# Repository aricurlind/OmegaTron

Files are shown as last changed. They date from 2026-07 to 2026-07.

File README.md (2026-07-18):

# Omega‑Tron – Autonomous Robot Vehicle  

Omega‑Tron is an autonomous robot vehicle developed as part of the M4000 project at Munich University of Applied Sciences.  
The system integrates **lane detection**, **obstacle avoidance**, **object detection**, **robot‑arm control**, **navigation**, and **inductive charging** into one modular platform powered by a Raspberry Pi 4B and Arduino Nano.

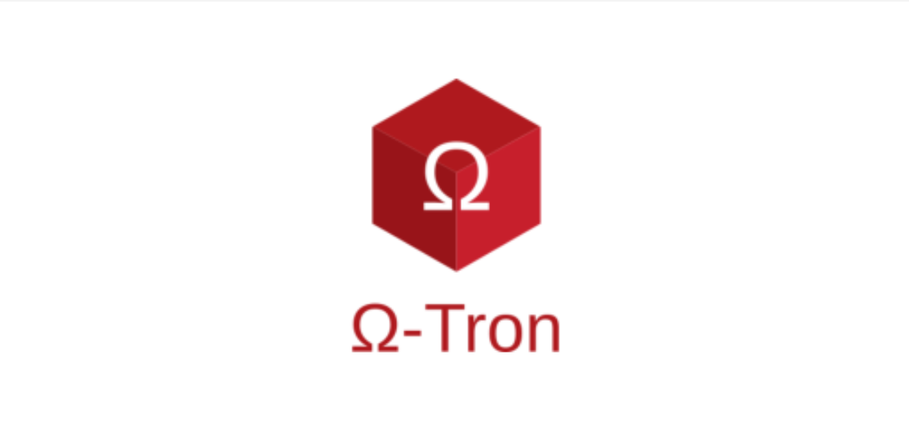
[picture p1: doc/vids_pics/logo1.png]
Omega Tron Logo
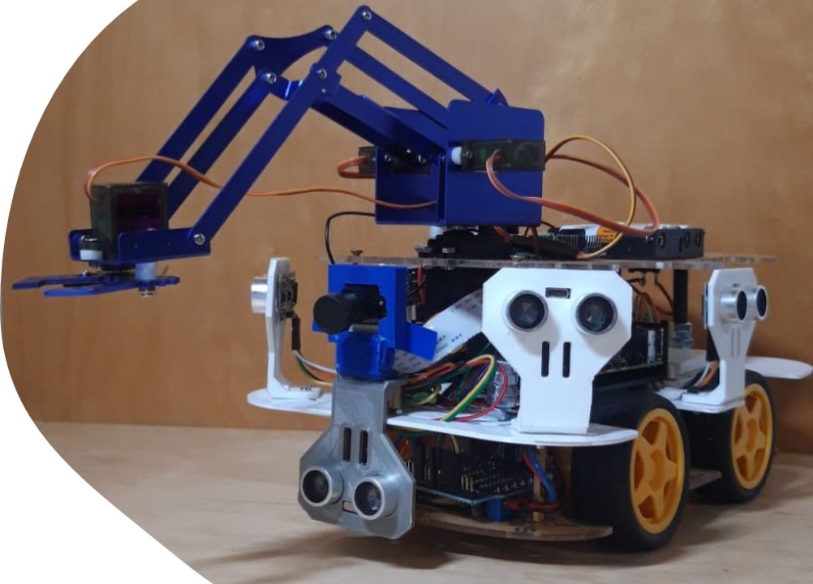
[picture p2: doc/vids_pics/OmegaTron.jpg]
Omega Tron
 

---

> **Note on images/videos below:** several media links in this README will not render on GitHub in their current form.

---

## Table of Contents
- [Project Overview](#project-overview)
- [System Architecture](#system-architecture)
- [Hardware Requirements](#hardware-requirements)
- [Software Requirements](#software-requirements)
- [Setup & Installation](#setup--installation)
- [YOLOv3 Training (Object Detection)](#yolov3-training-object-detection)
- [Running the System](#running-the-system)
- [Modules](#modules)

---

## Project Overview  
Omega‑Tron demonstrates how modern autonomous‑driving concepts can be implemented in a compact robotic system.  
The robot can:

- Detect and follow lanes  
- Avoid obstacles using 5 ultrasonic sensors  
- Identify objects (4 types of waste) using YOLOv3  
- Pick up objects with a 4‑DOF robot arm  
- Navigate using ROS odometry  
- Automatically dock to a charging station using a QR‑code marker
  
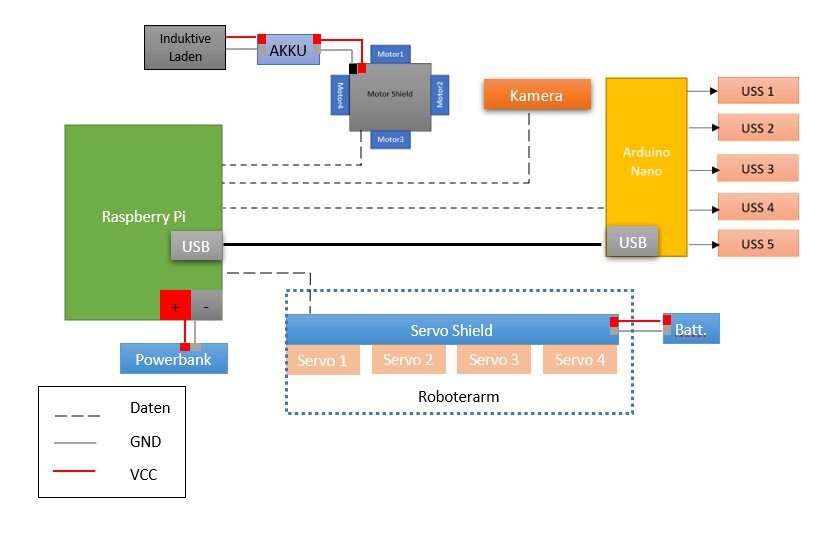
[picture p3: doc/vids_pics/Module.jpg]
Modules

---

## System Architecture  
The project is divided into several functional modules:

- **Lane Detection**  
- **Obstacle Avoidance**  
- **Object Detection**  
- **Robot Arm Control**  
- **Navigation & ROS**  
- **Inductive Charging**  

---

## Hardware Requirements  
### Core components (bill of materials)
| Component | Spec / Notes | Qty |
|---|---|---|
| Raspberry Pi 4B | 4 GB or 8 GB RAM recommended (YOLOv3 + OpenCV are memory-hungry) | 1 |
| microSD card | 32 GB+, A1/A2 rated for acceptable I/O speed | 1 |
| Arduino Nano | ATmega328P, USB-to-serial (CH340 or FTDI) | 1 |
| HC‑SR04 ultrasonic sensor | 2 cm–400 cm range | 5 |
| JOY‑IT DC gear motors | 6 V–12 V, with wheels | 4 |
| Arduino Motor Shield L293D | dual H-bridge, up to 4 DC motors | 1 |
| PCA9685 servo driver | 16-channel, I2C, 6 V servo rail | 1 |
| MG996R / MG905 servos | robot arm joints (base/shoulder/elbow/gripper) | 4 |
| Raspberry Pi Camera Module | v2 (8 MP) or HQ Camera, ribbon cable long enough to mount | 1 |
| Inductive charging coil set (Tx + Rx) | matched pair, 5 V/12 V output depending on design | 1 |
| QR-code marker (printed) | matte paper/laminated, fixed size, mounted at charging dock | 1 |
| Chassis / mounting plates | laser-cut or 3D-printed, drawings in `docs/` | 1 set |
| Battery pack (drive/logic) | separate rails recommended: ~7.4–11.1 V LiPo for motors, 5 V/3 A UBEC for Pi | 1–2 |
| Voltage regulator / UBEC | steps battery voltage down to a clean 5 V for the Pi | 1 |
| Jumper wires, perfboard, JST connectors | for all sensor/motor/servo wiring | as needed |
| USB cable (Pi ↔ Arduino Nano) | serial link for the 5 ultrasonic sensors | 1 |

### Special / non-obvious equipment
- **Soldering iron, solder, heat‑shrink tubing** – most connectors (motor shield, PCA9685, battery leads) are not solder‑free.
- **Multimeter** – required to verify the two power rails (motor vs. logic) before first power-on; a wiring mistake here can kill the Pi.
- **3D printer or laser cutter access** – only needed if you fabricate your own chassis instead of buying an off-the-shelf one; STL/DXF files should be placed in `docs/`.
- **A second computer with a GPU (or a Google Colab account)** – needed for YOLOv3 training, see below. Training on the Raspberry Pi itself is not practical.
- **USB keyboard/mouse + HDMI monitor, or SSH access over Wi‑Fi** – for initial Raspberry Pi OS setup if you don't use headless provisioning.

---

## Software Requirements

### Raspberry Pi (master)
- **OS**: Raspberry Pi OS (Bullseye or newer, 64‑bit recommended) — flashed with Raspberry Pi Imager.
- **Python**: 3.9+
- **Python packages** (see `requirements.txt` per module; consolidated list):
  - `opencv-python` (or `opencv-contrib-python` if you need extra modules)
  - `numpy`
  - `torch`, `torchvision` (CPU build is enough for inference on the Pi; training happens off-device, see below)
  - `pygame` (PS4 controller input during data collection)
  - `pyserial` (serial link to the Arduino Nano)
  - `pandas`, `matplotlib`, `scikit-learn` (lane-following CNN training/data logging)
  - `Adafruit-GPIO`, `RPi.GPIO` (motor shield + PCA9685)
- Interfaces to enable via `sudo raspi-config` before anything else works:
  - **Camera** (`Interface Options → Camera`, or `libcamera` stack on Bullseye+)
  - **I2C** (`Interface Options → I2C`) — required for the PCA9685 servo driver
  - **Serial port** (`Interface Options → Serial Port`) — enable the hardware serial, **disable** the serial login shell, or the Arduino link will fight with a getty process

### Arduino Nano (slave)
- **Arduino IDE** 1.8.x or 2.x, or `arduino-cli`
- Board package: **Arduino AVR Boards**
- No extra libraries needed beyond the built-in `Arduino.h` for the ultrasonic firmware (plain `pulseIn`-based ranging); if you swap in a library-based ultrasonic driver (e.g. `NewPing`), install it via Library Manager.

### Navigation (ROS)
- **ROS Noetic** (Ubuntu 20.04) is the natural fit for a Python-2/3-transition-era project like this; if you're starting fresh today, ROS 2 (Humble/Jazzy) is worth considering instead, but the odometry/mapping instructions in `navigation/` assume ROS 1 conventions (catkin workspace, `roslaunch`).
- ROS typically runs more reliably on a 64-bit Ubuntu Server image on the Pi (or a companion laptop acting as ROS master) than on Raspberry Pi OS; decide this before wiring your network setup.
- Packages: `ros-noetic-navigation`, `ros-noetic-robot-localization` (or equivalents) for odometry/mapping; a `catkin` workspace under `navigation/`.

### YOLO training (done off the robot)
- Python 3.9+ with `torch`, `torchvision` (GPU build) **or** a Google Colab notebook (free GPU, no local install needed)
- A labeling tool: **LabelImg** or **CVAT** or **Roboflow** (any of these can export YOLO-format annotations)
- `opencv-python`, `numpy`, `matplotlib` for dataset inspection/augmentation

---

## Setup & Installation

1. **Flash the Pi**
   Flash Raspberry Pi OS with Raspberry Pi Imager, boot, run `sudo raspi-config` and enable Camera, I2C, and Serial (hardware port on, login shell off) as listed above. Reboot.

2. **Clone the repository**
   ```bash
   git clone <this-repo-url> Omega-Tron
   cd Omega-Tron
   ```

3. **Python environment**
   ```bash
   python3 -m venv .venv
   source .venv/bin/activate
   pip install -r requirements.txt
   ```

4. **Wire the hardware**
   Follow the wiring diagram in `docs/` for: motor shield → DC motors, PCA9685 → servos, HC‑SR04 sensors → Arduino Nano, Arduino Nano → Pi (USB), camera → Pi camera port. Double‑check the two power rails with a multimeter before connecting the Pi.

5. **Flash the Arduino Nano**
   Open `obstacle_avoidance/uss_slave/uss_slave.ino` in the Arduino IDE, select **Board: Arduino Nano** and the correct **Port**, then upload. Confirm with the Serial Monitor (9600 baud) that five distance values are being printed in a loop.

6. **Calibrate the classical lane detector**
   Run the lane-detection script with its trackbar window enabled and adjust the bird's-eye-view region and HSV thresholds for your track/lighting before trusting the output.

7. **(Optional) Set up ROS for navigation/docking**
   Install ROS Noetic (or your chosen distro) on the Pi or companion computer, build the `navigation/` catkin workspace, and confirm odometry topics are publishing before attempting autonomous docking.

8. **Place trained YOLO weights**
   Copy your trained `.weights`/`.pt` and `.cfg`/class-name files into `object_detection/` (see training section below) — the repo does not ship pretrained weights.

---

## YOLOv3 Training (Object Detection)

The object detector is **not trained on the robot**. Typical workflow:

1. **Collect images** of the 4 target waste classes under conditions similar to the robot's camera (angle, lighting, background).
2. **Label** the images in YOLO format (one `.txt` per image with `class x_center y_center width height`, normalized) using LabelImg, CVAT, or Roboflow.
3. **Split** the dataset into train/val (and ideally a held-out test set).
4. **Train**:
   - Easiest path: open the provided training notebook in **Google Colab** (free GPU), mount your dataset from Google Drive, and run the training cells — no local GPU required.
   - Local path: install a CUDA-capable PyTorch build and run the training script on your own GPU machine.
5. **Export** the resulting weights and config/class files.
6. **Deploy**: copy the exported files into `object_detection/` on the Pi. Inference on the Pi runs on CPU (or via OpenCV's DNN module), so keep the input resolution modest (e.g. 320×320) to maintain a usable frame rate.

---

## Running the System

Exact entry points depend on what's committed under each module folder; as a general pattern:

```bash
# Obstacle avoidance only (bench test)
python3 obstacle_avoidance/uss_master.py

# Lane following only
python3 lane_detection/lane_main.py

# Full autonomous run (lane + obstacle + object pickup)
python3 main.py
```

Run each module standalone first to verify sensors/actuators individually before running the combined `main.py` — this saves a lot of debugging time when something is miswired.

---
## Modules

### Lane Detection  

**Classical approach** 

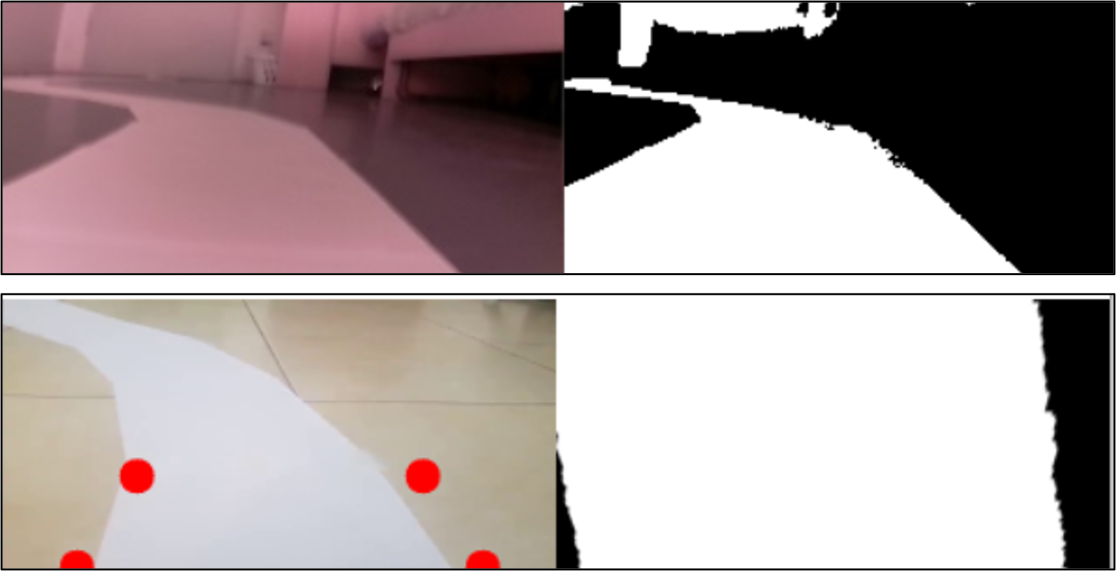
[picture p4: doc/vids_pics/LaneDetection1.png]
LaneDetection1


- Canny edge detection  
- Bird’s‑eye transformation  
- Histogram‑based lane center estimation  
- Hough transform for line detection  

📹 Demo video: [Media1](doc/vids_pics/Media1.mp4)

**Deep learning approach**

- Data collection during driving  
- CNN training on lane images  
- Output: steering angle prediction  

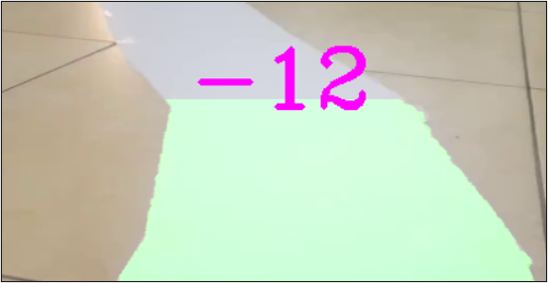
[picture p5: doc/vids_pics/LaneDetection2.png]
LaneDetection2
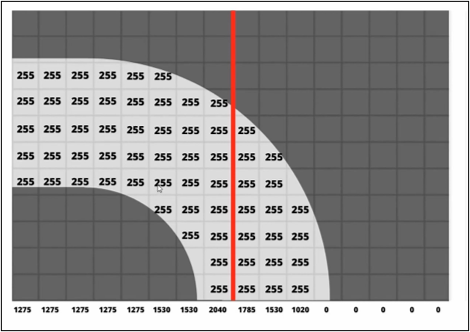
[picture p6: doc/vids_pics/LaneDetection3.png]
LaneDetection3
 

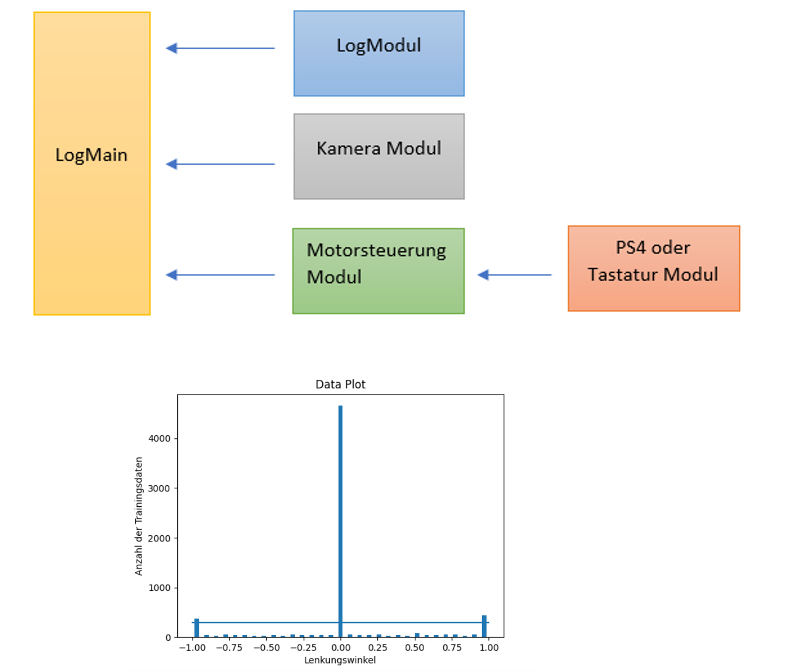
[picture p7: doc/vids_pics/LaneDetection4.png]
LaneDetection4

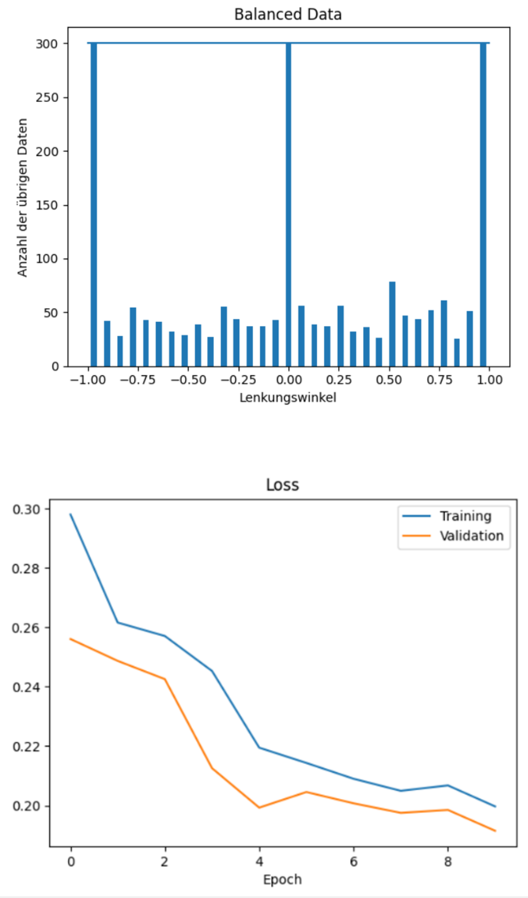
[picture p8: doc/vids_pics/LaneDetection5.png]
LaneDetection5


📹 Demo videos: [Media2](doc/vids_pics/Media2.mp4) · [Media3](doc/vids_pics/Media3.mp4)

---

### Obstacle Avoidance  

DistanceSensors2 

- 5 ultrasonic sensors controlled by Arduino Nano  
- Encoded distance values sent to Raspberry Pi  
- Python master interprets sensor data  
- Motor control decisions via AMSpi  

---

### Object Detection  

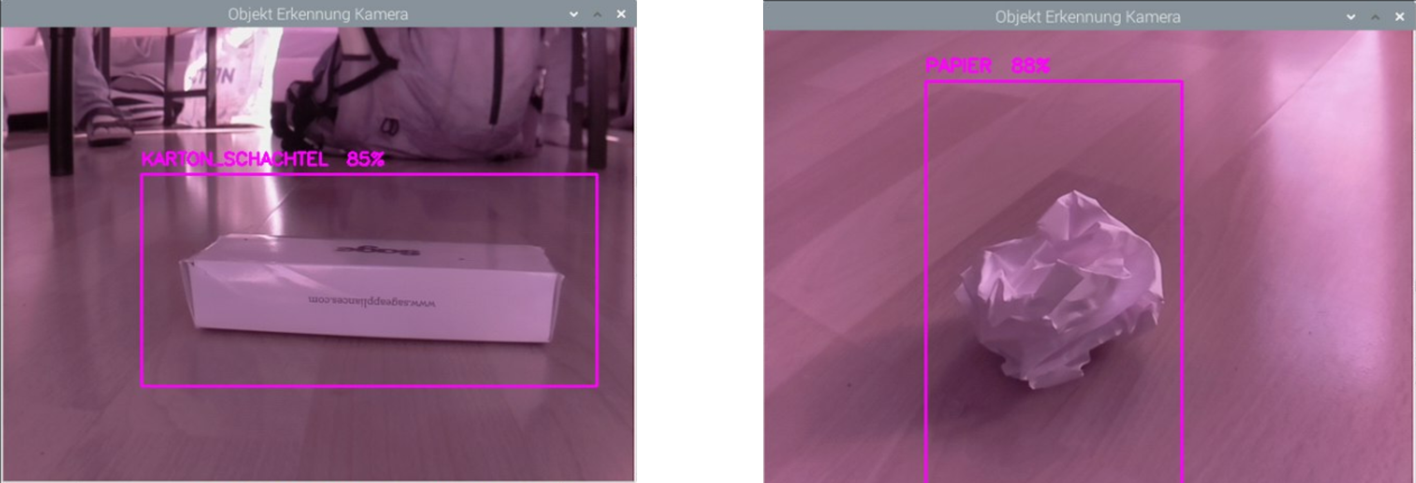
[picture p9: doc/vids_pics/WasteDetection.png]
WasteDetection
 

YOLOv3 identifies trash objects and provides bounding boxes.  
Detected coordinates are forwarded to the robot arm module.

---

### Robot Arm  

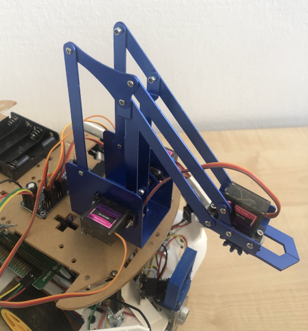
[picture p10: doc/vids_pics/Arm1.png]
RobotArm
 

- 4 degrees of freedom  
- MG996R / MG905 servos  
- PCA9685 for precise PWM control  
- Automated grasping based on object position  

📹 Demo video: [Media4](doc/vids_pics/Media4.mp4)

---

### Inductive Charging  
- Battery monitoring via GPIO  
- ROS navigation to charging station  
- Final alignment using QR‑code detection  

---

## 👥 Authors  
- Arlind Çurumi       - Team and SW Lead
- Christoph Häußler   - HW Integration Lead
- Jiang Qi Qiu  
- Ismail Güney  
- Munich University of Applied Sciences – Faculty of Mechanical Engineering - Mechatronics Laboratory

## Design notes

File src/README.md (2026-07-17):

# Omega-Tron – Autonomes Roboterauto

## Projektstruktur

```
OmegaTron/
├── main.py                       # Verbindet Fahrspurfolge, Hindernisumfahrung und Müllsammlung
├── requirements.txt               # Laufzeit-Abhängigkeiten (Pi)
├── requirements-dev.txt           # + pytest für Entwicklung/Tests auf einem PC
├── Common/
│   ├── config.py                 # Zentrale Konfiguration (Schwellwerte, Regler-Gains)
│   ├── pid.py                    # Generischer PID-Regler mit Anti-Windup
│   ├── filters.py                # Median- und Kalman-Filter für Sensordaten
│   └── video_stream.py           # Threaded Kamera + feste Regelschleifen-Taktung
├── tests/                        # pytest-Suite mit gemockter Hardware (RPi.GPIO, cv2)
│   ├── conftest.py
│   ├── test_pid.py
│   ├── test_filters.py
│   ├── test_ultraschallsensoren.py
│   ├── test_motortreiber_mixing.py
│   └── test_waste_collector.py
│
├── Motorsteuerung/
│   ├── AMSpi.py                  # Open-Source Bibliothek für Arduino Motor Shield L293D
│   ├── Motortreiber.py           # Fahrbefehle (vorwärts, rückwärts, links, rechts, ...)
│   └── hand.py                   # Manuelle Tastatursteuerung via Pygame
│
├── Hindernisumfahrung/
│   ├── USS_Master.py             # Raspberry Pi Master – liest serielle USS-Daten und steuert Motoren
│   └── USS_5.ino                 # Arduino Nano Slave – liest 5 Ultraschallsensoren
│
├── Fahrspurerkennung/
│   ├── AlgorithmusOhneDL/
│   │   ├── LaneDetection.py      # Hauptskript – Fahrspurerkennung ohne Deep Learning
│   │   ├── Hilfsfunktionen.py    # HSV-Filter, Warping, Histogramm, Visualisierung
│   │   └── Farbengenerator.py    # Tool zum Einstellen der HSV-Grenzwerte
│   │
│   ├── Datensammlung/
│   │   ├── LogMain.py            # Hauptskript – Bilder + Lenkwerte aufzeichnen (PS4-Controller)
│   │   ├── LogModul.py           # Speichert Bilder und CSV-Log
│   │   └── KameraModul.py        # Kamera-Wrapper
│   │
│   ├── Training/
│   │   ├── Training.py           # CNN-Training nach NVIDIA-Architektur
│   │   └── Hilf_Func.py          # Datenladen, Augmentation, Preprocessing, Modell, Generator
│   │
│   └── MitDL/
│       └── Omega_Tron_CNN_Main.py  # Autonome Fahrt mit trainiertem CNN-Modell
│
├── Objekterkennung/
│   ├── Obj_Detection.py          # YOLOv3-Erkennung + Bounding Box Anzeige
│   ├── Detection_Modul.py        # Schnittstelle Kamera → Erkennung → Roboterarm
│   └── train_yolov3_custom.py    # YOLOv3-Training in Google Colab (kommentiert)
│
└── Roboterarm/
    ├── Adafruit_PCA9685.py       # PWM-Controller-Bibliothek für PCA9685
    └── ModulRoboterarm_aktuell.py  # Roboterarm-Steuerung (Start, Greifen, Wegwerfen)
```

## Hardware

- Raspberry Pi 4B (Master)
- Arduino Nano (Slave – Ultraschallsensoren)
- Arduino Motor Shield L293D
- 4x DC-Motoren
- 5x Ultraschallsensoren (USS)
- Raspberry Pi Kamera
- PCA9685 PWM-Controller
- 4-DOF Roboterarm mit Servos
- PS4-Controller (für manuelle Steuerung / Datensammlung)

## Erkannte Objektklassen

| ID | Klasse |
|----|---|
| 0  | Bio-Müll |
| 1  | Metallische Dose  |
| 2  | Papier |
| 3  | Karton/Schachtel  |
| 4  | Plastik |

## Regelung, Filterung & Nebenläufigkeit

- **PID statt Bang-Bang**: Fahrspurlenkung (main.py) und Objektzentrierung
  (Detection_Modul.py) verwenden `Common/pid.py` statt fester
  Geschwindigkeit "Richtung Fehler". Gains sind Startwerte und müssen am
  Fahrzeug getunt werden.
- **Sensorfilterung**: Jeder Ultraschallsensor läuft durch einen eigenen
  Medianfilter (`Common/filters.py`), der einzelne Fehlmessungen abfängt.
  Ein Kalman-Filter für ein 1D-Konstantwert-Modell steht ebenfalls bereit.
- **Feste Zykluszeit**: `Common/video_stream.py` entkoppelt die
  Kameraaufnahme (Hintergrundthread) von der Regelschleife und taktet
  Letztere über `FixedRateLoop` auf eine feste Frequenz, da die PID-Regler
  eine konsistente dt erwarten.
- **Recovery-Verhalten**: `Ultraschallsensoren.py` versucht bei
  Verbindungsabbruch einen Reconnect statt abzustürzen;
  `Detection_Modul.py` wiederholt die Greifsequenz bei einem I2C-Fehler,
  bevor sie aufgibt.

## Tests

```bash
pip install -r requirements-dev.txt
pytest tests/
```

Hardwareabhängige Module (RPi.GPIO, cv2) werden in `tests/conftest.py`
gemockt, damit die reine Logik (PID, Filter, Decodierschema, Mixing-Mathematik,
State Machine) ohne Pi/Kamera/Arduino läuft.

## ML-Training

`Fahrspurerkennung/Training/` nutzt inzwischen einen echten
Train/Val/Test-Split, Dropout/BatchNorm, EarlyStopping und
ReduceLROnPlateau. Jeder Lauf legt unter `runs/<timestamp>/` sein Modell,
den Trainingsverlauf (`history.csv`) und die verwendeten Hyperparameter
(`config.json`) ab – kein vollwertiges Experiment-Tracking wie MLflow/W&B,
aber genug, um Läufe nachvollziehen zu können.

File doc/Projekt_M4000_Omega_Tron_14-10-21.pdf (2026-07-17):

## Hochschule München University of Applied Sciences

## Fakultät für Maschinenbau, Fahrzeugtechnik und Flugzeugtechnik

### Projektarbeit M4000

### Entwicklung und Programmierung von Modellrobotern

# Ω-Tron

Verfasser : | Çurumi, Arlind
| Häußler, Christoph
| Qiu, Jiang Qi
| Güney, Ismail
Studiengang: | Maschinenbau, MBB 6
Betreuer: | Prof. Dr. T. Küpper
| Prof. Dr. J. Reichel
Abgabetermin: | 13.10.2021

## Inhaltsverzeichnis

6.5 Datenblätter | Fehler! Textmarke nicht definiert.

### 1 Einleitung

### 1.1 Aktuelle Entwicklungstrends im Bereich Autonomes Fahren

Die Automobilindustrie befindet sich in einem massiven und komplexen, vor allem aber sehr dynamischen Wandel. Die Entwicklung neuer Fahrtechnologien, die Digitalisierung und das Aufkommen neuer Geschäftsmodelle haben diesen Veränderungsprozess bestimmt und ein einzelnes Auto zu einem Kommunikationselement gemacht, das über Internet, Sensoren und Kameras mit seiner Umwelt interagiert. Dadurch können neue Player in den Markt eintreten und die Automobilindustrie von Grund auf verändern. Der harte, globale Wettbewerb um den Markt von morgen hat bereits begonnen.

Seit Anfang des letzten Jahrzehnts haben sich Automobilhersteller und ihre Zulieferer der Umsetzung des autonomen Fahrens verschrieben. Viele Testfahrzeuge mit unterschiedlichen Assistenzsystemen wurden weltweit in eigens dafür geschaffenen Testgebieten getestet und teilweise auch im realen Straßenverkehr ordnungsgemäß gekennzeichnet. Obwohl der Begriff „Auto“ die eigenständige Fortbewegung eines Fahrzeugs beschrieben hat, haben selbstfahrende Autos den Begriff der Autonomie präzisiert und in eine neue Dimension gehoben.

Selbstfahrende Autos bewegen sich durch das Zusammenspiel von Mikroprozessorsystemen, Sensoren und Aktoren gezielt selbstständig. Um autonomes Fahren zu realisieren, müssen viele technische Herausforderungen bewältigt werden.

Videokameras der Umgebung , Verkehrszeichen und anderen Teilnehmern. Außerdem helfen sie dem autonomen System, die Entfernung zu Objekten richtig einzuschätzen

Radarsensoren messen den Abstand zu anderen Verkehrsteilnehmern und Objekten. Low- und
High-Range-Sensoren | berechnen | dabei | die
unterschiedlichen | Entfernungen. | Deshalb

benötigt ein Auto mehrere davon - an verschiedenen Stellen. Lidar-Sensoren (Light Detection and Ranging) (https://de.wikipedia.org/wiki/Lidar) auf dem Dach tasten die vorausliegende Strecke ab. Das optische Messsystem feuert für den Menschen unsichtbare Laserstrahlen ab und berechnet den Weg der von einem Hindernis reflektierten Rückstrahlen. Lidar-Sensoren verwenden zur Messung Laserstrahlen statt Radiowellen, wie beim Radar. Ihr Vorteil: die hohe Reichweite.

Mit einem GPS-System wird das Auto genau geortet. Das System weiß immer, wo es sich gerade befindet - nicht nur auf welcher Straße, sondern auch auf welcher Spur. Das ist für abbiegende Fahrzeuge entscheidend.

Doch ein Autonomes Fahrzeug ist weitaus mehr als eine reine Fortbewegungsmittel. Sie kann auch als eine komplettes Mobilitätskonzept, aus dem wir neue Geschäftsmodelle entwickeln können,

Abbildung 1: Sensortopologie für Autonome Fahrzeuge entwickelt werden. Sie kann individuell konfiguriert werden damit Sie für alle Aufgabenstellungen innerhalb des Urbanen Umfelds einsetzbar sein kann.

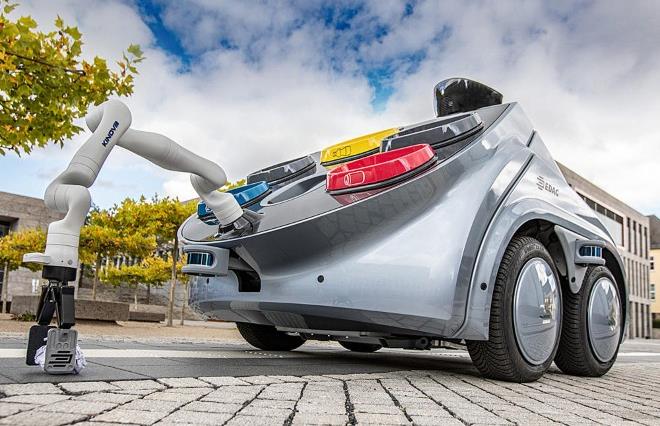
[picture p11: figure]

Abbildung 2: Edag Citybot ©Edag

Solche vernetzten vollautonom fahrenden Roboterfahrzeuge werden zum Beispiel zur Abfallsammlung und Straßenreinigung genutzt. Das Roboterfahrzeug bekommt eine Information, wo welcher Mülleimer zu leeren ist, fährt autonom dort hin und erledigt diese Aufgabe selbstständig. Er kann die unterschiedlichen Abfallsorten durch Künstliche Intelligenz einsortieren und somit richtig entsorgen.

Weitere Konfigurationsmodelle, sind z.B. Roboterfahrzeuge, welche die Post zustellen wie der Roboter-Postbote von Amazon oder das multimodale Citybot-Konzept von EDAG .

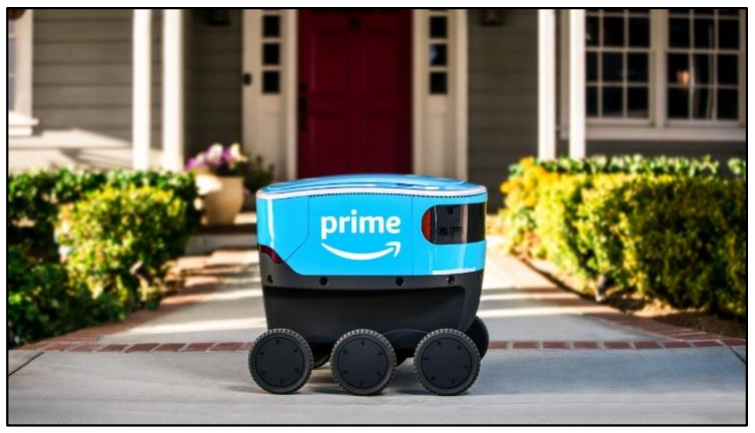
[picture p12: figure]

Abbildung 3: Amazon Scout Postbote ©Amazon

Aufgrund des breiten Anwendungsbereichs und dem wachsenden Interesse an Themen wie autonomes Fahren, Bilderkennung und künstliche Intelligenz haben wir uns dazu entschieden, diese Themenbereiche auch in unserer Projektarbeit zu bearbeiten. Wir hoffen darauf, dass wir uns durch die praktischen Erfahrungen wichtige Kompetenzen für die Zukunft aneignen zu können.

### 1.2 Projektumfang und Kurzfassung

Ziel dieser Projektarbeit ist es, die aktuellen Entwicklungstrends aus dem Bereich autonomes Fahren, in einem Miniroboter Modellauto auf Basis von Raspberry Pi umzusetzen. Als Rechner Einheit wird ein Raspberry Pi 4B eingesetzt, welches das zentrale Element zur Steuerung der verschiedenen Module ist. Umfang der Projektarbeit war es, die elektrische Verschaltungen auszulegen, sowie Module für die Motorsteuerung, eine Fahrspurerkennung, Objekterkennung, die Steuerung des Roboterarms, Ermittlung des Ladezustands, Ansteuerung der Ultraschallsensoren und der Navigation des Roboters zu programmieren.

### 2 Projektplanung

### 2.1 Anforderungen und Zielsetzung

Die Anforderungen und die Zielsetzung wurde durch eine Untergliederung des Gesamtsystems ermittelt. Hierfür wurden die drei Teilsysteme Roboterauto, Objekterkennung und der Roboterarm spezifiziert. Die Schnittstellen haben sich durch diese Spezifizierung folgendermaßen ergeben:

Schnittstelle Roboterauto – Fahrspurerkennung

Schnittstelle Roboterauto – Hindernisumfahrung

Autonomes Fahren

Das Roboterauto hat als Hauptaufgabe in erster Linie die Vorwärts-, Rückwärts- und Seitenbewegung zu gewährleisten. Ziel ist es, am Ende ein voll autonom fahrendes Auto inklusive folgende Anforderungen aufzubauen:

- Hindernisumfahrung
- Fahrspurerkennung
- Objekterkennung

Abfallsammlung

Der Roboterarm ist ein auf dem Roboterauto aufgebautes System, welches vor allem für die Funktion des Greifens verantwortlich ist. Hierbei wird insbesondere durch die Schnittstelle Objekterkennung und Roboterarm Abfall aufgesammelt und entsorgt. Abgesehen vom Greifen ist es besonders wichtig, dass auch der Roboterarm automatisiert und ohne manuelle Bedienung funktioniert und den Greiferarm nutzen kann.

### 2.2 Konzeptideen

2.2.1 Fahrspurerkennung

Für das autonome Fahren wurde ein Algorithmus zur Fahrspurerkennung entwickelt. Dieser Algorithmus basiert auf der Hough Transformation, ein robustes Verfahren zur Erkennung von beliebigen geometrischen Figuren in einem binären Gradienten Feld. Hier handelt es sich um Geradenerkennung und berechnung der mittleren Spur zur Fahrspurverfolgung. Des weiteren wurden Datensätze gesammelt und mit ihnen trainiert, um den Roboter das Fahren einzulernen. Dafür wird ein vereinfachter CNN-Ansatz verwendet.

2.2.1.1 Bild Verarbeitung

Die Fahrspurerkennung ist einer der zentralen Bestandteile von autonomen Fahrzeugen. Es gibt viele Ansätze, um einen Fahrspurerkennung Algorithmus auszulegen. Dabei handelt es sich um das automatisierte Identifizieren der eigenen Fahrspur durch Fahrbahnmarkierungen oder andere Umgebungsmerkmale, die durch verschiedene Sensoren- und Kameras erfasst werden. Auf dem Markt gibt es einige Fahrzeuge, die über diese beiden Funktionen verfügen, nämlich den Abstandsregeltempomat (ACC) und einige Formen von Spurhaltesystemen (LKAS). Der Abstandsregler nutzt verschiedene Radarsensoren, um einen sicheren Abstand zum vorausfahrenden Fahrzeug zu erkennen und einzuhalten, während die Spurhalteassistenzsysteme mittels Kameras die Fahrspur erkennen und das Fahrzeug so lenken, dass es in der Mitte der Fahrspur bleibt.
In diesem Projekt wird ein einfacher Algorithmus zur Erkennung von parametrisierbaren geometrischen Figuren in einem binären Gradienten Bild nach einer Farbenerkennung der der Fahrspur verwendet. Dadurch wird eins einfaches und robustes Konzept zur Erkennung der Fahrspur entwickelt.

Es wurden insgesamt zwei Algorithmen entworfen, welche beide auf die Hough Transformation basieren.

Die erste Algorithmus beinhaltet die folgenden Schritte:

(1) Bildverarbeitung zum Erkennen der Fahrspur durch Kannten Erkennung
(2) Kanten Erkennung Algorithmus (Canny Edge Detektion)
(3) Ausblenden von Bildbereichen, die nicht gewünscht sind (z.b. Objekte auf Seiten der Fahrspur)
(4) Hough Transformation Algorithmus
(5) Erzeugen von Fahrspurbegrenzungslinien zum Bilden der linken und rechten Fahrspur (Abb.4)

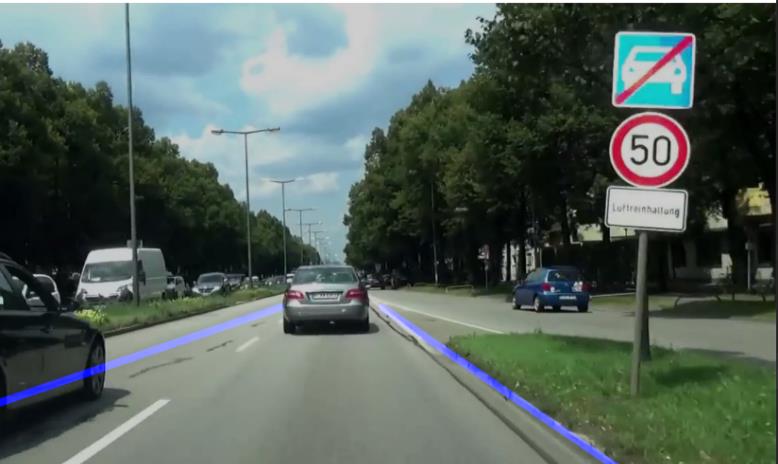
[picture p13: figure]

Abbildung 4: Fahrspurverfolgung durch Kantenerkennung mit Hough Transformation Quelle: Eigene Darstellung

Der zweite Algorithmus beinhaltet die folgenden Schritten(Abb.5):

(1) Bildverarbeitung zum Erkennen der Fahrspur durch Farbenunterschiede (Color Detection)
(2) Kamerabildtransformation in Vogelperspektive (Birdseyeview)
(3) Pixelaufsummierung zum Identifizieren der Fahrspur
(4) Bestimmung der Fahrspurmittellinie

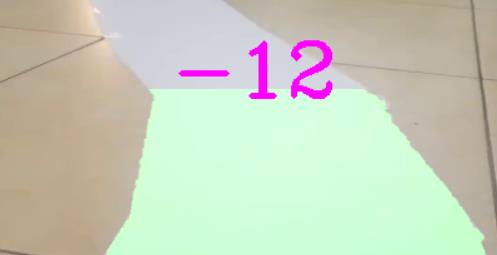
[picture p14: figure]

Abbildung 5: Fahrspurerkennung durch Farbenerkennung. Quelle: Eigene Darstellung

2.2.1.2 Convolutional Neural Networks

Deep Learning ist ein Teilbereich des maschinellen Lernens, der sich mit Algorithmen befasst, die von der Struktur und Funktion des Gehirns inspiriert sind und als künstliche neuronale Netze bezeichnet werden. Im maschinellen Lernen werden Algorithmen, um eine bestimmte Aufgabe zu erledigen, ohne explizit programmiert zu werden. Anders als im maschinellen Lernen, sind Deep Learning Modelle in der Lage von sich aus zu lernen. Das passiert, in dem die Systeme das Erlernte immer wieder mit neuen Inhalten verknüpfen und dadurch erneut lernen. Bei Lernvorgang von neuronalen Netzen wird das Analysieren der neuen Daten der Maschine überlassen.

Deep-Learning Algorithmen sind Tiefe neuronale Netze und bestehen aus vielen Schichten aus linearen und nicht linearen Datenverarbeitungseinheiten.

In diesem Projekt wird auch eine Deep Learning Model angewendet, um den Modellroboter das Fahren einzulernen. Das verwendete Modell ist Convolutional Neural Network.

Ein CNN (Convolutional Neural Network) ist eine besondere Form der künstlichen Neuronalen Netzwerks die in der Bildverarbeitung und -erkennung verwendet wird. Sie ist speziell für die Verarbeitung von Pixel-Daten konzipiert.

Bei CNN Modellen werden die Eingabebilder verarbeitet und auf Bestimmten Kategorien klassifiziert. Diese Eingabebilder werden vom Computer als eine Matrix von Pixeln interpretiert. Die Größe dieser Matrix ist von Bildauflösung Abhängig.

Jedes Eingabebild, wie in Abb.6 zu sehen ist, läuft eine Reihe von verschiedenen Faltungsschichten (Eng. Layer) durch.

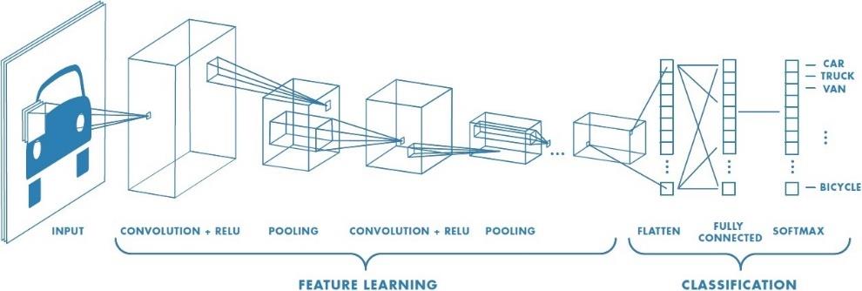
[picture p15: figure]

Abbildung 6: CNN Schichten

Die „Convolutional Layer“ ist die erste Schicht zur Extraktion von Merkmalen aus einem Eingangsbild. Diese Layer-Schicht bewahrt die Beziehung zwischen Pixeln, indem sie Bildmerkmale anhand kleiner Quadrate von Eingabedaten lernt. Es handelt sich um eine mathematische Operation, die zwei Eingaben wie eine Bildmatrix und einen Filter oder Kernel benötigt.

Die Schichten einer CNN sind eine Kombination aus Faltungsschichten, Pooling-Schichten, Normalisierungsschichten und vollständig verbundenen Schichten. CNNs verwenden mehrere Faltungsschichten, um Eingabevolumen auf einem höheren Grad an Abstraktion zu filtern. CNNs verbessern ihre Erkennungsfähigkeit für ungewöhnlich platzierte Objekte, indem sie Pooling-Schichten für eine begrenzte Translations- und Rotationsinvarianz verwenden. Pooling ermöglicht auch die Verwendung von mehr Faltungsschichten, indem es den Speicherverbrauch reduziert. Normalisierungsschichten werden verwendet, um lokale Eingangsbereiche zu normalisieren, indem alle Eingaben in einer Schicht auf einen Mittelwert von Null und eine Varianz von Eins gebracht werden.

Andere Techniken zur Anpassung wie z.b. „Batch“-Normalisierung bei der die Aktivierungen für den gesamten Faltungssatz normalisiert werden, oder die Dropout-Technik, bei der zufällig ausgewählte Neuronen während des Trainingsprozesses ignoriert werden, können ebenfalls verwendet werden.

Im Kapitel 3.4.2.2 Training der Daten wird nochmal an das Training mit CNN angegangen und die einzelnen inneren Prozesse einer CNN-Modell nochmal mit Beispielen aus der trainierten Fahrspurerkennungsmodell der Omega-Tron erläutert.

2.2.2 Hindernisumfahrung (Obstacle Avoidance)

Wie im Abschnitt 2.2.1.1 erwähnt, verwendet man verschiedene Radarsensoren und Kameras beim Autonomen Fahren verwendet, um die Fahrspurerkennung zu ermöglichen. Um ein Fahrspurhaltesystem zu entwickeln, braucht man verschiedene Kameras und einen Algorithmus, das fähig ist Daten zuverlässig und in Echtzeit zu verarbeiten. Für den Abstandsregeltempomat (ACC) braucht man keine Kameras, jedoch wird hier auch ein Algorithmus benötigt. Dies wird benötigt um verschiedene Sensoren wie Radar-, Lidar- und Ultraschallsensoren zu steuern. Die verschiedenen Sensoren dienen dazu die Position und Geschwindigkeit des vorausfahrenden Fahrzeugs zu ermitteln.

In diesem Projekt wurde ein einfacher Algorithmus zur Erkennung von Objekten, die relativ nah zum Omega-Tron sind, verwendet. Dafür wurden keine hochwertigen Sensoren wie Radaren oder Lidar verwendet, sondern nur Ultraschallsensoren. Davon wurden 5 Stück um das Auto montiert und um den Robotermodell so montiert, dass man eine volle Abdeckung des Fahrzeugs hat.

Für das Umsetzen des Konzeptes wurden 2 Konzepte entworfen:

(1) Steuern aller 5 Sensoren über Raspberry Pi
(2) Steuern aller Sensoren von Arduino Nano und das Herstellen einer Master-Slave Kommunikation zwischen Raspberry Pi 4 und Arduino Nano.

Für das erste Konzept wird eine einfache Steuersoftware in Python benötigt, sowie ein Spannungswandler. Da Raspberry Pi mit 3.3V Logik arbeitet und die Ultraschallsensoren aber eine 5V Logik haben, wird eine entsprechenden Anpassung des Spannungsniveaus benötigt.

Abbildung 7: Verbindung der Raspberry Pi mit 5 USS

Beim zweiten Konzept werden die Ultraschallsensoren von einem Microcontroller gesteuert. Da der Arduino Nano eine 5V Logik hat, wird hier kein Spannungswandler benötigt. In Abb.8 sieht man die serielle Verschaltung des Raspberry Pi mit einem Arduino Nano über ein USB-Kabel.

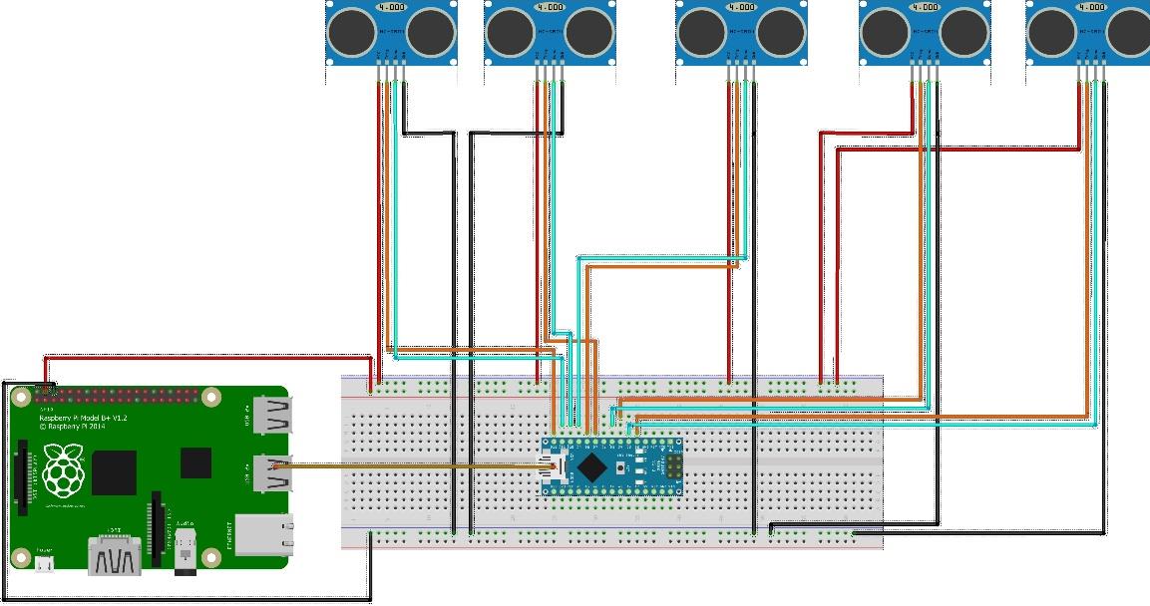
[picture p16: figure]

Abbildung 8: verbindung der Raspberry Pi mit Raspberry Pi Pico (Hier Arduino Nano)

2.2.3 Objekterkennung zur Abfallsammlung

Immer mehr übernehmen Computer in den verschiedensten Gebieten menschliche Aufgaben. Ein großer Bereich ist das maschinelle Lernen von Bilddaten. Egal ob das Erkennen von Fehlern bei der Produktion von SMD Platinen, die Führung eines Fahrzeugs auf der Fahrspur oder ganz groß wie in China: Das Identifizieren von Personen in der Öffentlichkeit, das automatische Erkennen von Objekten findet heute schon ganz große und wichtige Anwendung.

Ganz bekannt und einfach zu verstehen ist Image Classification. Dabei wird dem System ein Bild vorgelegt und dieses soll erkennen, um was es sich auf dem Bild handelt. Objekt Detection geht da noch ein Schritt weiter: Dabei werden um einzelne Objekte sogenannte „Bounding Boxes“ gelegt und einzeln identifiziert.

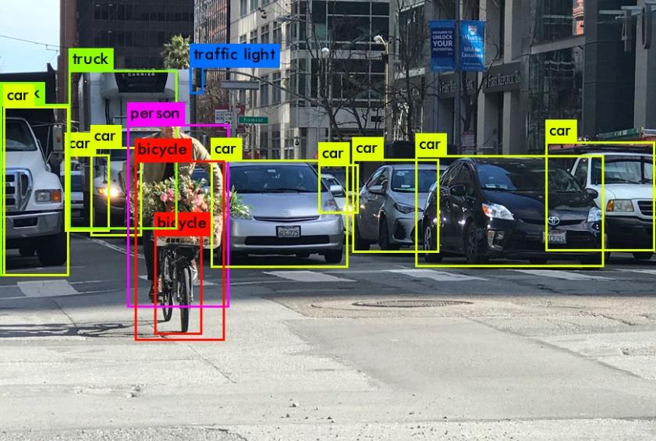
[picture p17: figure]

Abbildung 9: Objekt- und Positionserkennung von Fahrzeugen im Straßenverkehr

YOLO ist eine Möglichkeit, um Objekte zu erkennen. 2016 stellten Redmon, Divvala, Girschick und Farhadi erstmal ihre einstufige Architektur namens „You Only Look Once“ zur Objekterkennung in Echtzeit vor. Durch das Zusammenführen der Lokalisierung und Erkennung mehrerer Objekte innerhalb einer Ebene der Architektur, konnten so schnelle Inferenzzeiten erzeugt werden.

Mittlerweile gibt es verschiedenste Versionen von YOLO. Für unsere Anwendung nutzen wir YOLOv3, welches wie gefolgt funktioniert:

1. Das Bild wird in die Pixelgröße 416x416 Pixeln skaliert und ins Netz eingespeist
2. Dabei durchquert das Bild verschiedenen Schichten von Neuronen
3. Convolutional Network: Neuronen mit einem Filter wie z.B. 3x3 Zelle fährt über das ganze Bild um Merkmale zu erkennen
4. Endauflösung in je 13x13, 26x26 und 52x52 Zellen mit Informationen über das Bild
5. Pro Zelle werden 3 Bounding Boxes gezogen mit je 85 (Geometrie 4, Objekthaftigkeit 1, 80 Klassen) Werten
6. Über 10 000 Bounding Boxes werden durch Non-Maximum Suppression auf wenige reduziert
7. Bounding Boxes mit den schlechtesten Bewertugen werden rausgeschmissen
8. Finale Vorhersage mit je einer Bounding Box und Label

2.2.4 Motorensteuerung

Abbildung 10: Links Getriebe Motor, Rechts Motorshield

Zur Steuerung der vier JOY-IT Getriebemotoren haben wir ein Arduino Motor Shield L293D gewählt welches wir mit Hilfe der Python Klasse AMSpi (https://github.com/lipoja/AMSpi#readme) steuern. Die Klasse verfügt über Befehle zum einzelne Motoren mit Drehrichtung und Geschwindigkeit anzusteuern. Mit diesen Befehlen haben wir eine Motorsteuerung programmiert, mit der man einfache Richtungsbefehle geben kann oder auch eine Geschwindigkeit und einen Lenkwinkel stufenlos vorgeben kann. Mit diesen Befehlen und der Hilfe der pygame Bibliothek, haben wir dann noch ein Programm geschrieben, um den Roboter mit den aus Computerspielen intuitiven Tastatureingaben zu steuern. Die Funktion für Lenkwinkel und Geschwindigkeit wurde noch bei der Fahrspurerkennung genutzt.

2.2.5 Ortung und Navigation

Zur Navigation des Roboters wird ROS(Robot Operating System) verwendet durch ROS erhält man Zugriff auf verschiedenste Module zur Robotersteuerung. Verwendet wird das Odometry Package zur Positionsbestimmung des Roboters. Das Modul vereinigt Eine Integration der Steuerungsdaten sowie Beschleunigungsdaten der IMU(InternalMesurementUnit). Mit Hilfe der Ultraschallsenesordaten mappt das Modul TIAGo den Raum und navigiert autonom durch die selbst erstellte Karte.

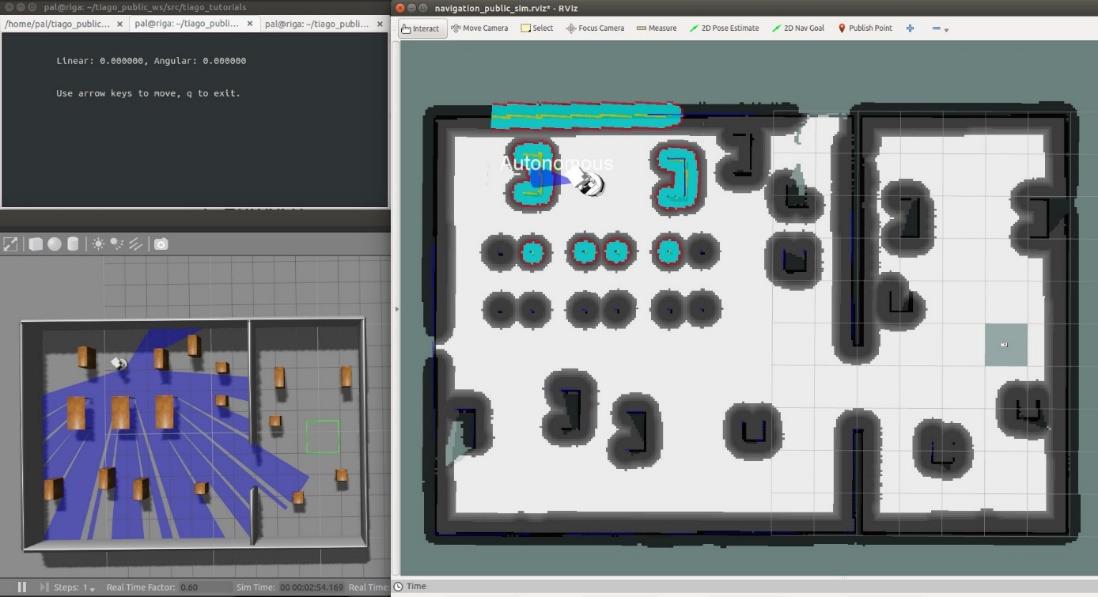
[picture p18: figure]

Abbildung 11: Beispielbild TIAGo Map

2.2.6 Roboterarm

Beim Roboterarm ist die Entscheidung sehr schnell auf einen Greiferarm mit vier Freiheitsgraden und Servomotoren als Antrieb für diese gefallen. Hierbei musste man auf die Art des Servomotors Acht geben, da nicht alle Gelenke des Roboterarms die gleiche Versorgung beziehungsweise manche Gelenke mehr Power als andere benötigen. Hierbei handelt es sich um die Servomotoren MG905 und MG996R. Für die Schnittstelle zum Raspberry Pi wurde der Servotreiber PCA9685 mit 16 Kanälen als beste Lösung auserkoren. Die Verbindung zwischen dem Raspberry Pi und dem Servotreiber wurde über Jumper Kabel realisiert. Die Servomotoren wurden schließlich mit dem Servotreiber verbunden und die Kanäle definiert.

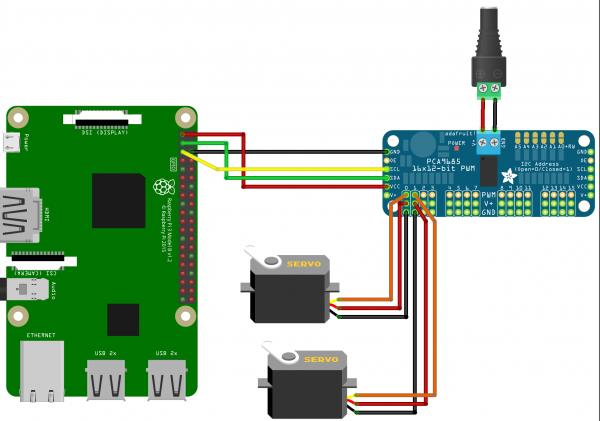
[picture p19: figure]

Abbildung 12: Schaltschema Servomotoren

Des Weiteren war bei der Realisierung wichtig einzuplanen, wo und wie der Roboterarm und der Servotreiber auf dem Auto eingebaut wird. Letztendlich wurde dazu entschieden, den Greifer und Treiber auf die höchste Ebene des Roboters zu montieren.

Abbildung 13: Roboterarm

2.2.7 Induktives Laden
Das induktive Laden wird durch eine Ladespule am Boden des Roboters realisiert. Der Roboter navigiert mit Hilfe der Ordometriedaten/mit ROS grob zur bekannten Position der Ladestation, wenn die mit einem GPIO verbundene Ladeplatine einen niedrigen Akkustand meldet. Die exakte Positionierung findet über die Kamera, die einen QR-Code über der Station erkennt, statt.

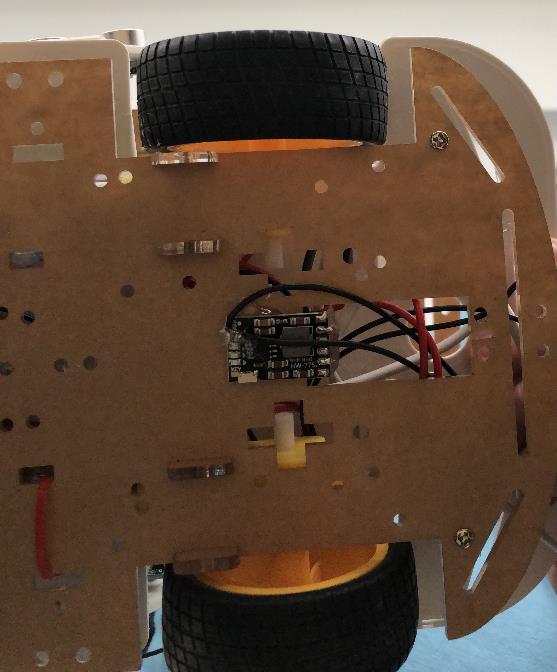
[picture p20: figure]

Abbildung 14: Ladeplatine mit Verkabelung Ladezustandsmessung

### 3 Konzeptentwicklung

### 3.1 Konzeptentwicklung für die Hindernisumfahrung

Beim Entwicklung des Hindernisumfahrung Konzeptes wurde beide Konzept Ideen aus der Konzeptphase ausprobiert und getestet.

Beim Ersten Konzept ging es um eine Steuerung aller 5 Sensoren direkt von Raspberry Pi. Beim Umsetzen und Testen des Steuerungssoftware wurde festgestellt, dass das Senden und Empfangen der Signale vom Raspberry Pi an die Sensoren und Rückwärts viel zu langsam ist. Außerdem gab es Komplikationen bei der Verschaltung der einzelnen Pins von der Ultraschallsensoren zu Raspberry.

Abbildung 15: Raspberry Pi 4 Kommunikation mit USS

Um die Oberen 2 Probleme zu lösen, wurde das zweite Konzept ausprobiert und getestet, nämlich das Steuern der Ultraschallsensoren von einem Microcontroller und das Herstellen einer Master-Slave Kommunikation zwischen den Microcontroller und Raspberry Pi .

Abbildung 16: Raspberry Pi I2C mit Raspberry Pico

Erstmals wurde versucht eine Serielle Kommunikation zwischen den Raspberry Pi und Raspberry PI Pico herzustellen. Es wurde versucht eine I2C Serielle Kommunikation zwischen den beiden Herzustellen. Nach mehreren Testcodes und versuchen hat sich herausgestellt, dass das Herstellen der Kommunikation aufgrund von Bibliotheken Problemen zwischen Python 3 (In Raspberry Pi) und Micro Python (in Raspberry Pico ) nicht möglich war. Da man beim Raspberry Pi Pico au noch in C/C++ programmieren kann wurde auch noch ein letztes Versuch durchgeführt. Hierfür wurde die Programmierungsumgebung von Arduino IDE verwendet. Bei der Steuerung der Sensoren, war das Senden und Empfangen der Daten deutlich schneller, jedoch hat die Kommunikation zwischen Pi und Pico wiederum nicht zuverlässig funktioniert.

Die andere Möglichkeit war das Verwenden einer Arduino Nano zur Steuerung der Sensoren. Die Verbindung der Arduino zu Raspberry wurde mittels USB-Datenkabel ganz simpel und problemlos hergestellt.

Abbildung 17: Raspberry PI Serielle Kommunikation mit Arduino Nano

Die Kommunikation zwischen den Raspberry und dem Arduino lief zuverlässig und reibungslos. Die Serielle Kommunikation wurde auf einen Baudrate von 9600 eingestellt. Über die Python serial() Bibliothek werden die von Arduino Nano Print-Befehle ausgelesen.

Die Werte die Raspberry von Arduino liest werden in die Variable Botschaft gespeichert. Um zu unterscheiden welche Sensor welche Wert geschickt hat, wurde eine ID Wert an die Sensoren zugewiesen. Außerdem wurde in Arduino die Reichweite der Sensoren begrenzt, die können alle jeweils bis 500 cm Reichweite auslesen. Die ID-s wurden wie Folgend definiert:

Sensor Vorne | → | 0 | < | Gelesene Wert | < | 500
Sensor Rechts Vorne | → | 500 | < | Gelesene Wert + 500 | < | 1000
Sensor Links Vorne | → | 1000 | < | Gelesene Wert + 1000 < | 1500
Sensor Rechts | → | 1500 | < | Gelesene Wert + 1500 < | 2000
Sensor Links | → | 2000 | < | Gelesene Wert + 2000 < | 2500

Im Raspberry Pi wurde dann eine Code, die je nach gelesene ID in die Zugehörige Variable die Werte speichert. Um dann das Fahrzeug zu steuern, wurden If-Anweisungen geschrieben, die beim Vergleichen von Entfernungen in eine Definierte Reichweite den Modellroboter lenken.

### 3.2 Computer Vision Schnittstelle

3.2.1 Entwicklung eines Algorithmus zur Fahrspurerkennung

Ein Fahrspurassistenzsystem besteht aus zwei Grundbausteinen, nämlich Fahrspurerkennung (Wahrnehmung der Umgebung) und der Lenkung (Bewegungsplanung).

Die Aufgabe der Fahrspurerkennung besteht darin, ein Video der Straße in die Koordinaten der erkannten Fahrspurlinien umzuwandeln. Um dies zu erreichen, wird des Weiteren das Open-Source Package OpenCV benutzt.

Bevor wir jedoch Fahrspurlinien in einem Video erkennen können, müssen wir in der Lage sein, Fahrspurlinien in einem einzelnen Bild zu erkennen. Sobald wir das können, ist die Erkennung von Fahrspurlinien in einem Video eine einfache Wiederholung der gleichen Schritte für alle Bilder in einem Video.

Um diese Spurhalteassistenzsystem zu entwickeln, wurden die folgenden 5 Schritten benötigt:

i. Bild Verarbeitung zum Erkennen der Fahrspur (Color Detection)

Als erster Schritt muss eine Bildverarbeitungsmethode durchgeführt werden, um die Fahrspur zu erkennen. Dies kann man durch Erkennung von Farbenunterschieden ermitteln.

Da die von der Kamera aufgenommenen Frames einen RGB-Farbenspektrum haben, wird dies in den HSV-Farbenspektrum umgewandelt. Die von OpenCV erfassten Bilder und Videos sind in der Regel im BGR-Format (8-Bit, Ganzzahl ohne Vorzeichen). Anders gesagt können die Erfassten Bilder als 3 Matrizen betrachtet werden: BLAU, ROT und GRÜN mit ganzzahligen Werten zwischen 0 und 255. Bei einem Bild wird jeder einzelne Pixel dann verschiedene Kontrasten von diese 3 Farben haben.

Der Grundgedanke dahinter ist, dass in einem RGB-Bild verschiedene Farben dazu führen, dass die verschiedenen Farben durch Beleuchtungen oder andere Umgebungseinflüsse nicht richtig erkannt werden. In HSV-Farbenspektrum werden alle Objekten aus der Umgebung als Schwarz-Weiß dargestellt. Der HSV-Farbraum besteht aus 3 Matrizen, Hue, Saturation und Value. In OpenCV ist der Wertebereich für die 3 Matrizen jeweils 0-179, 0-255 und 0-255. „Farbton“ (Eng. Hue) steht für die Farbe, „Sättigung“ (Saturation) für den Anteil, in dem die jeweilige Farbe mit Weiß gemischt ist, und „Wert“ (Eng. Value) für den Anteil, in dem die jeweilige Farbe mit Schwarz gemischt ist.

Das macht das Erkennen der Fahrspurlinie Pixel für Pixel viel leichter. Im Abb.5 ist eine Vergleich der Fahrspur in HSV und RGB Farbenspektrum Dargestellt

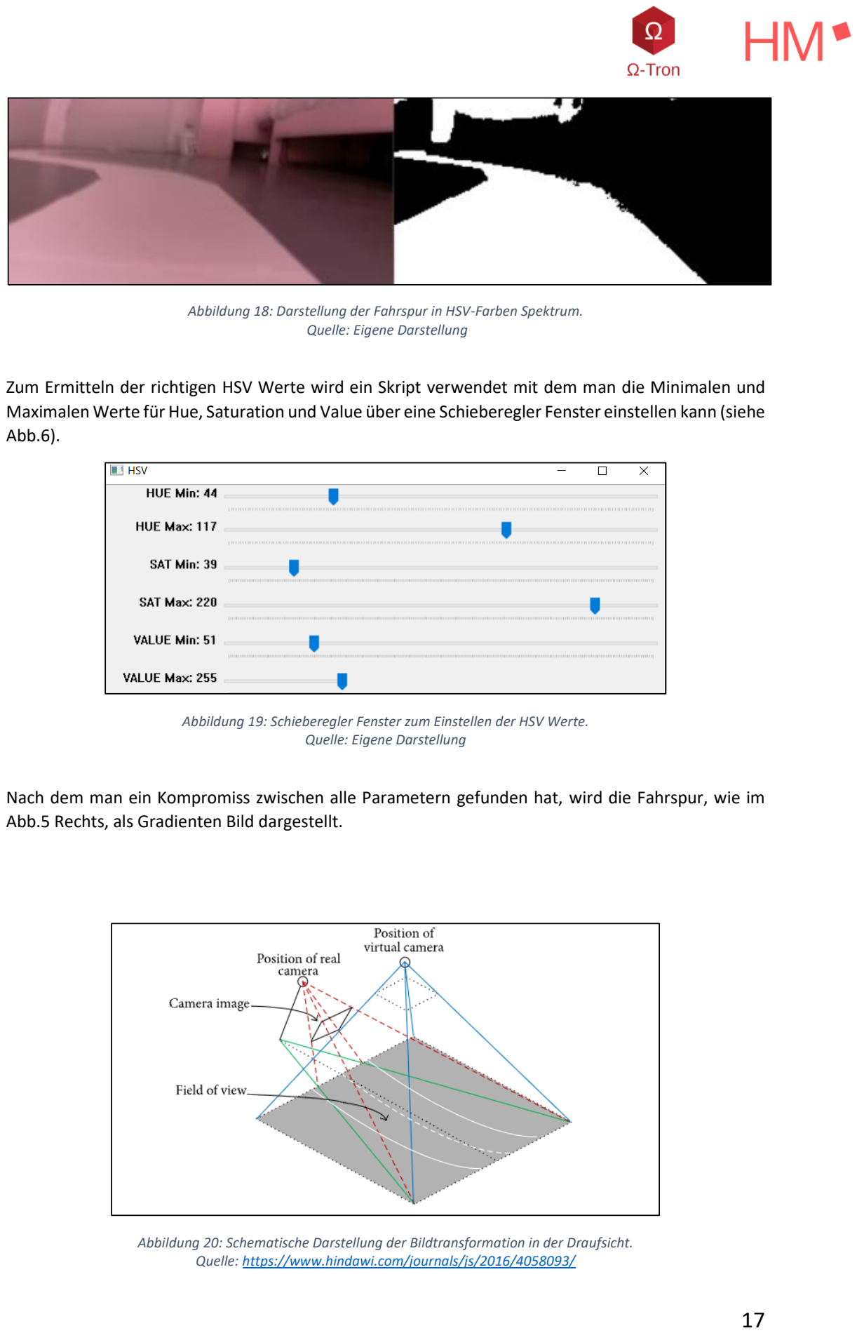
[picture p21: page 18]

Abbildung 18: Darstellung der Fahrspur in HSV-Farben Spektrum. Quelle: Eigene Darstellung

Zum Ermitteln der richtigen HSV Werte wird ein Skript verwendet mit dem man die Minimalen und Maximalen Werte für Hue, Saturation und Value über eine Schieberegler Fenster einstellen kann (siehe Abb.6).

Abbildung 19: Schieberegler Fenster zum Einstellen der HSV Werte. Quelle: Eigene Darstellung

Nach dem man ein Kompromiss zwischen alle Parametern gefunden hat, wird die Fahrspur, wie im Abb.5 Rechts, als Gradienten Bild dargestellt.

Abbildung 20: Schematische Darstellung der Bildtransformation in der Draufsicht. Quelle: https://www.hindawi.com/journals/js/2016/4058093/

ii. Kamerabildtransformation in Vogelperspektive (Birdseyeview)

Durch diese Transformation des Bildes kriegt man eine Draufsicht auf die Fahrspur (siehe Abb.7). Dieser Schritt ist auschlaggebend und dadurch wird eine präzise und effektive Erkennung der Fahrspurenkurven ermöglicht. Der Grundgedanke ist, dass mit einer Perspektive von oben der Algorithmus besser entschieden werden kann, in welche Richtung die Fahrbahn geht und wie weit die nächste Kurve ist. Um das Bild geschickt für unsere Anwendung zu verzerren, wird das OpenCV Funktion getperspektiveTransform() benutzt. Der Funktionen benötigen zwei Eingaben:

- Die Koordinaten der aktuellen Bild pro Frame (Abb.8 links)
- Die Koordinaten der zu transformierenden Bild pro Frame (Abb.8 rechts)

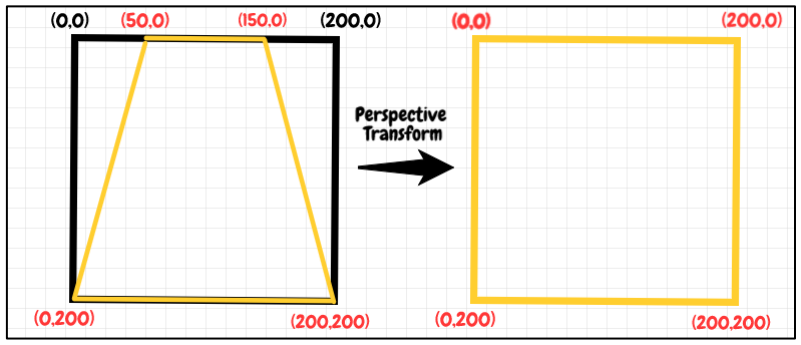
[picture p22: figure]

Abbildung 21: Perspektive Transformation. Quelle: medium.com (https://medium.com/analytics-vidhya/opencv-perspective-transformation-9edffefb2143)

Die Koordinaten des aktuellen Bildes werden manuell eingestellt. Diese müssen so eingestellt werden, dass bei jeder Lenkung der Omega-Tron die unteren zwei Koordinaten des Vierecks immer in der Fahrspur liegen. Die Oberen zwei Koordinaten werden so eingestellt, dass die nicht zu weit, aber auch nicht zu nah mit den unteren sind. Diese zwei Punkte sind ausschlaggebend für die Lenkung des Autos. Wenn diese weit genug von den unteren Koordinaten sind, hat das Fahrzeug genug Zeit, um das nächste Lenkungsmanöver zu ermitteln. Wenn diese aber zu weit oder zu nah sind, kann das zu Verwirrungen führen, da die Fahrspurlinien dann nicht richtig erkannt werden.

Abbildung 22: Koordinaten der Aktuellen Bild (Links) und mit Transformierte Koordinaten in HSV-Farben (Rechts). Quelle: Eigene Darstellung

Da das manuelle Einstellen der Koordinaten schwierig sein kann, wird genauso wie im vorherigen Schritt, ein Schieberegler Fenster verwendet. Damit kann man die Koordinaten in Echtzeit an das Bild einstellen. Dafür wurden die OpenCV Funktionen cv2.createTrackbar() und cv2.getTrackbarPos() verwendet. Damit man diese Punkte genauso wie in Abb.9 (Links) darstellen kann, wird die Funktion cv2.Circle() verwendet.

Der finale Schritt ist dann, die Koordinaten aus der getperspektiveTransform() an die OpenCV Funktion warpPerspektive() zu schicken. Dadurch kriegt man einen Birdseyeview der Fahrspur wie in Abb.9 zu sehen ist.

iii. Pixeln Aufsummierung zum Identifizieren der Fahrspur

Dieser Schritt und der nachfolgende sind die wichtigsten bei der Fahrspurerkennung. Hier wird ein Algorithmus entworfen, mit dem Omega-Tron die Mitte der Fahrspur berechnen kann und somit einen Pfad verfolgen kann. Dies wird durch die sogenannte Pixel Summation Methode erreicht, die in Abb.6 dargestellt ist.

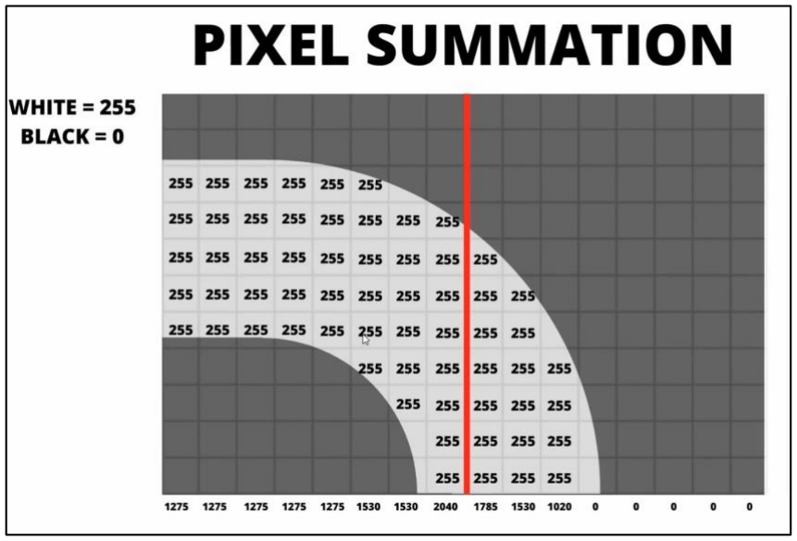
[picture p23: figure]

Abbildung 7: Pixeln Aufsummierung. Quelle: @Murtaza'sWorkshop

Da das verzerrte Birdseyeview Bild nun binär ist, d. h. es hat entweder schwarze oder weiße Pixel, kann man die Pixelwerte in y-Richtung summieren, um Aussagen über die Fahrspurmittelline zu treffen. Wie im oberen Bild dargestellt haben alle weißen Pixel einen Wert von 255 und die schwarzen einen Wert von 0.

Wenn man nun die Pixel in der ersten Spalte addiert, erhält man 1275. Diese Methode wird auf alle Spalten angewendet. In dem ursprünglichen Bild hat die Breite 480 Pixel. Daher ergeben sich 480 Werte. Nach der Summierung lässt sich feststellen, wie viele Werte über einen bestimmten Schwellenwert liegen, beispielsweise 1000 auf jeder Seite der mittleren roten Linie. Im obigen Beispiel gibt es 8 Spalten auf der linken und 3 Spalten auf der rechten Seite. Dies bedeutet, dass die Kurve nach links verläuft. Dies ist das grundlegende Konzept wie Omega-Tron die Fahrspur verfolgen kann.

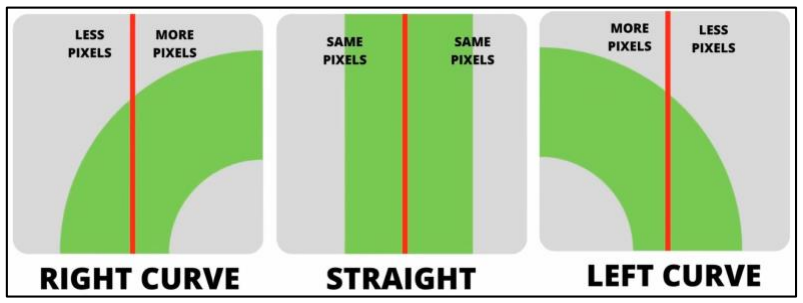
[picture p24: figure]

Abbildung 23: Aufsummierung der Pixeln zur Kurven Verfolgung. Quelle: https://easychair.org/publications/preprint_download/4DRl iv. Bestimmung der Fahrspur Mittellinie (Hough Transformation durch Pixel Summation)

Durch den Vorherigen Schritt wurde es erläutert wie das Auto durch Pixel Aufsummierung die Fahrspur verfolgen kann und somit entschieden kann, ob Sie nach links oder nach rechts lenkt.

Jedoch kann es passieren, dass es beim Fahren einer geraden Straße mehr weiße Pixel nach rechts als nach links gibt oder andersherum. In diesem Fall würde das Auto nach links bzw. nach rechts Lenken, was falsch wäre. Diese Fehler entstehen, da im vorherigen Schritt als Mitte der Fahrspur, die Mitte des Aufgenommenen Bildes verwendet wurde, was also eine fester Wert.

Dieses Problem kann leicht behoben werden, indem man die Mitte der Fahrspurlinie über den Mittelwert der weißen Pixeln in der Fahrspur ermittelt. Anhand von dieser berechneten Mittellinie werden dann genau wie im obigen Schritt die Pixeln nach links und rechts aufsummiert, um die Lenkkurve zu finden. Einfacher gesagt, die Fahrspurmitte und der benötigte Lenkwinkel wird für jede Frame berechnet, um die besten Lenkwerte zu bekommen.

Wenn die Kurve rechts ist, ist es wichtig zu wissen, wie weit rechts. Um den Wert der Krümmung zu ermitteln, sucht man die Indizes aller Spalten, deren Wert über einen gewissen Schwellenwert liegt, und bildet dann den Durchschnitt der Indizes.

Die Schwellenwert wird anhand von Versuchen festgelegt. Das ist der Mindestwert, der für jede Spalte erforderlich ist, um als Teil des Pfades und nicht als Rauschen zu gelten.

Die Berechnung des Fahrspur Mittelpunktes wurde in den Funktion getHistogram() mi der Variable CurvenMittelwert definiert.

v. Implementierung

Für das Implementieren wird ein Main Skript geschrieben. In diesem Skript wird das Kameramodul, das Fahrspurerkennungsmodul und das Motormodul aufgerufen.

Um das Fahrzeug geschickt zu lenken, wird beim Aufrufen des Fahrspurerkennungsmoduls eine Sensitivität und ein Geschwindigkeitsfaktor vordefiniert. Dies dient dazu, dass das Fahrzeug beim Fahren der Kurve nicht bei jeder Frame nach links und nach rechts lenkt, sondern nur dann, wenn ein maximaler Kurven Wert überschritten wird.

Abbildung 24: Auszug aus der Implementierung der Algorithmus

3.2.2 Umsetzung einer Deep Learning Model zum Fahrspurerkennung

3.2.2.1 Datensammlung

Der Erste Schritt, um Omega-Tron das Autonome Fahren beizubringen, ist Daten zu sammeln. Diese Daten werden dann benutzt, um ein Deep Learning Model zu trainieren. Um einen Algorithmus der Fahrspurerkennung zu lernen und somit das autonome Lenken beim Fahren, braucht man Lenkungsdaten und die entsprechenden Bilder dazu, wo der Modellroboter ein Lenkungsmanöver durchführt.

Um die Daten zu sammeln, wurde das Python Skript LogModul geschrieben in die Bilder und Excel Protokolldaten mit dem Bild, Name und dem entsprechenden Lenkwinkel dazu. Dieses Skript wird dann im Main Skript zum Sammeln der Daten aufgerufen, das LogMain Skript. Hinzu ruft diese Funktion noch die Module zur manuellen Steuerung von Omega Tron, sowie auch das Kamera Modul Skript.

Im LogMain werden diese dann jeweils aufgerufen und mit einem definierten Tastenbefehl wird das Aufzeichnen gestartet und gestoppt. Das Steuern von dem Roboter erfolgt entweder per Tastaturbefehl oder mit einem PS4 Controller. In Abb. 19 ist noch ein Schema des benötigten Skripts, die das LogMain Modul zum Datensammlung benötigt.

3.2.2.2 Training der Daten

Das Training der Datensätze kann man in 10 einfachen Schritten erklären.

1- Importieren der Daten Pfade

Die gesammelten Datensätze, die Bilder aus der Fahrspur mit die Entsprechenden Lenkungswerte, werden im Training Skript als Pfade geladen. Hier werden diese als Pandas Dataframes importiert. Ein Pandas Dataframe ist eine einfache Darstellung der Daten in einer Tabelle mit Reihen und Spalten. Die zwei Spalten sind die Lenkungswerte aus der Excel Datei und die Pfade der entsprechenden aufgenommenen Bilder. Der Vorteil hier ist, dass bei der Bearbeitung dieser Daten, nicht direkt auf das Dataset zugegriffen wird, sondern nur auf den Dateipfad. Zum Beispiel wenn man einige Daten aus der

LogMain

PS4 oder
Tastatur Modul

Motorsteuerung
Modul

Kamera Modul

LogModul

Abbildung 25: Schema der Datensammlung Programm Code

Pandas Liste löschen will, werden nur die Pfade gelöscht und diese Dateien werden im Training einfach nicht mehr verwendet. An einem späteren Zeitpunkt wären diese Daten dann wieder greifbar. In Abb. 12 sind die ersten 5 Daten aus einer Gesamtanzahl von 6659 zu sehen.

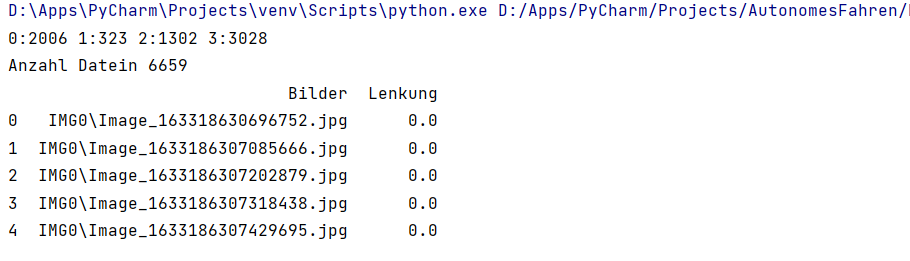
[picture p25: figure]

Abbildung 26: Auszug aus der Daten Import

2- Visualisierung und Anpassung der Daten

Bevor man die Daten trainiert ist es wichtig eine Visualisierung des Datensatzes durchzuführen. Hier wurde festgestellt, dass die Mehrheit der Bilder und Lenkungswert sind, wenn der Roboter geradeaus gefahren ist(siehe Abb.13). Im Vergleich zu den anderen Werten hat diese Kategorie viel mehr Daten und ist somit ungleichmäßig. Je ungleichmäßiger ein Datensatz ist, desto ungenauer wird das trainierte Modell am Ende sein, da dieses sehr stark auf eine Kategorie trainiert wurde, als die andere. In diesem Fall würde das Model, dass geradeaus fährt sehr gut lernen, aber die restlichen Lenkungsmanöver wären nicht so gut trainiert.

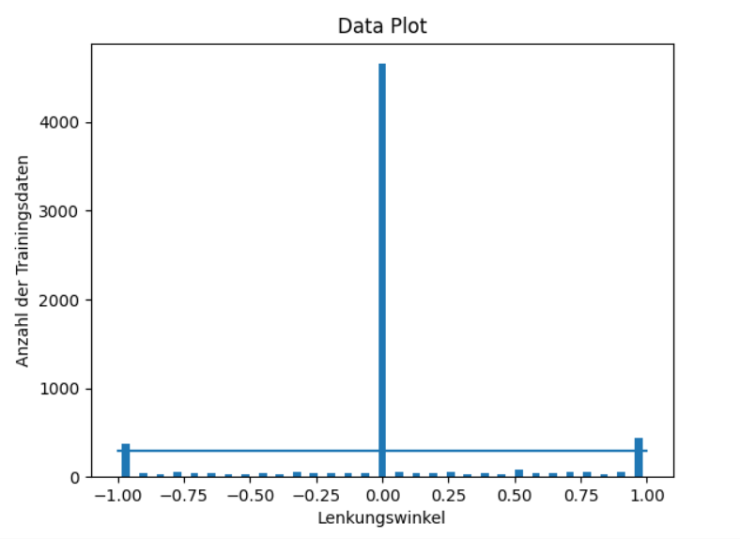
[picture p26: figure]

Abbildung 27: Visualisierung der Daten

Um dies zu vermeiden, werden die Daten balanciert. In diesem Fall wurden alle Kategorien mit mehr als 300 Daten geschnitten. Nach diesem Prozess wird die Datenmenge pro Lenkungsstärke wie unten aussehen.

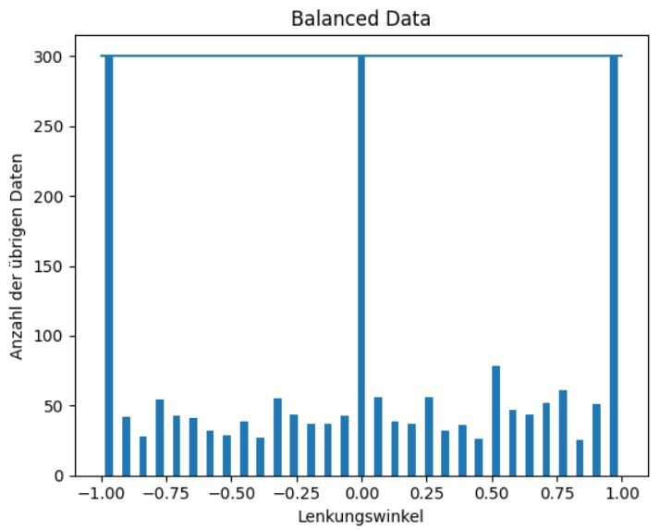
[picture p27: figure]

Abbildung 28: Ausgeglichene Daten

3- Laden der eigentlichen Daten zum Trainieren

In diesem Schritt werden alle Daten, die aus dem Schnitt 2 nicht geschnitten wurden, hochgeladen, um diese dann in den kommenden Schritte zu trainieren. Im Unterschied zu Schritt 1 werden hier die physikalischen Daten hochgeladen, nicht nur die Adressen und die Inhalte davon.

4- Aufteilung der Daten in Training und Validierungsdaten

Bevor man die bereits hochgeladenen Daten trainiert, ist es wichtig den Datensatz in Trainings- und Validierungsdatensätze aufzuteilen. Dies macht man, um die Effizienz des zu trainierenden Algorithmus abzuschätzen und zwar durch das Anwenden der von dem Trainingsdaten trainierten Modell auf Daten, die nicht zum Trainieren des Modells verwendet wurden, nämlich die Validierungsdaten. Um den Aufteilungsprozess (Eng. Split) leichter zu machen wird die Python Bibliothek Scikit-Learn verwendet.

Demnach werden die Daten in x und y aufgeteilt. Hier handelt es sich um einen „Unsupervised Learning“ Algorithmus, indem die Maschine den Zusammenhang der Lenkungsdaten mit den Bildern selbst entdeckt und versucht ein Modell dafür zu trainieren. Man hat Eingabevariablen (x) und Ausgabevariablen (y), mit dem der Algorithmus die Verknüpfung von der Eingabe zur Ausgabe lernt.

Die Lenkungsdaten sind also mit der entsprechenden Bildaufnahme zu diesem Lenkungsmanöver in der Excel-Datei verknüpft und der Algorithmus wird so trainiert, dass er selbst entscheidet, wann der beste Moment ist, in Bezug auf das Bild was es von der Kamera bekommt, um ein Lenkungsmanöver durchzuführen.

Der Datensatz wurde in 80% Trainingsdaten und 20% Validierungsdaten aufgeteilt. Die Daten werden zufällig aufgeteilt und es gibt keinen Auswahlprozess.

In Abb.16 ist die Anzahl der Daten, die für das Training und Validierung verwendet wurden zu sehen. Außerdem sieht man auch die Anzahl der Bilder, die während Schritt-2 geschnitten wurde.

Abbildung 29: Auszug aus der Programcode

5- Daten Augmentieren

Die Datenaugumentierung heißt nichts anderes, als nur Originalbilder zu modifizieren. Während der Fahrt kann sich die Fahrspurerkennung als schwierig erweisen, falls die Beleuchtung sich ändert oder eine Kurve zu eng ist und die Kamera nicht mehr die ganze Fahrspur sehen kann. Äußerem kann man in diesem Schritt den Datensatz durch das Erzeugen von diesen zusätzlichen Dateien erhöhen. Es handelt sich aber nicht nur um die Anpassung der Lichthelligkeit und Bildgröße, sondern auch um das Umdrehen des Bildes, was einen erheblichen Einfluss auf den Trainingsprozess hat.

Es werden auf Zufallsbasis 50% aller Daten augmentiert.

6- Anlegen eines Farbenfilters für den Trainingsdatensatz (Preprocessing)

Genau wie in Schritt 5 handelt es sich hier um Datenaugmentierung. Der Unterschied zu Schritt 5 ist, dass es sich hier um ein Bildverarbeitungsprozess handelt, welches auch im Fahrspurerkennung Kapitel 3.4.1 Absatz i) verwendet wurde. Das „Preprocessing“ ist ausschlaggebend für die Farbenerkennung da hier die verschiedenen Filter angelegt werden mit dem das Fahrzeug danach die Fahrspur erkennt.

7- Erstellen eines CNN Model für das Training der Daten

Hier befindet sich man beim wichtigsten Schritt des Deep Learning Modells zur Fahrspurerkennung, das Erstellen eines CNN-Modells. Das hier verwendete Modell basiert auf das NVIDIA Deep Learning Modell für Autonome Fahrzeuge. In Abb. 17 ist der Aufbau der Faltungsschichten, des Nvidia Modell zu sehen.

Die Gewichte des Netzwerks werden so trainiert, dass der mittlere quadratische Fehler zwischen dem vom Algorithmus ausgegebenen Lenkbefehl und dem durch den Augmentieren angepassten Lenkbefehl, minimiert wird.

Abbildung 30: NVIDIA CNN Model Quelle: @Nvidia.com

Das NVIDIA Model besteht aus 9 Schichten, darunter eine Normalisierungsschicht, 5 Faltungsschichten und 3 vollständig verbundene Schichten.

Die erste Schicht des Netzes führt eine Bildnormalisierung durch. Der Normalisierungsmechanismus ist fest kodiert (Eng. Hard-coded) und wird während des Lernprozesses nicht angepasst.

Die Faltungsschichten sind für die „feature extraction“ konzipiert und werden empirisch durch eine Reihe von Experimenten mit unterschiedlichen Schichtkonfigurationen ausgewählt. In den ersten drei Faltungsschichten werden geschichtete Faltungen mit einem 2×2 „Stride“ und einem 5×5 Kernel und in den letzten beiden Faltungsschichten eine nicht-„strided“ Faltung mit einer 3×3 Kernelgröße verwendet.

„Stride“ ist ein Parameter des Filters des neuronalen Netzwerks, der den Bewegungsanteil im Bild oder Video verändert. Wenn der „Stride“ eines neuronalen Netzwerks beispielsweise auf 1 eingestellt ist, bewegt sich der Filter jeweils um ein Pixel bzw. eine Einheit. Die Größe des Filters wirkt sich auf das kodierte Ausgabevolumen aus, daher wird „stride“ oft auf eine ganze Zahl und nicht auf einen Bruchteil oder eine Dezimalzahl eingestellt.

Auf diese fünf Faltungsschichten folgen dann drei vollverknüpfte Schichten, die zu einem endgültigen Ausgabesteuerungswert führen. Die vollverknüpften Schichten sind so konzipiert, dass sie als Controller für die Lenkung des Modell Roboter dienen.

8- Trainings des Models

Nach dem Erstellen des Models werden alle Prozessen aus der vorherigen Schritte in einen Funktion zum Trainieren der Daten aufgerufen. Der Funktion wurde als dataGen() definiert.

Zum Aufrufen der Funktion werden „Batches“ definiert. „Batches“ sind Hyperparameter, der die Anzahl der zu verarbeitenden Daten festlegt, bevor die internen Modellparameter aktualisiert werden. Ein „Batch“ lässt sich als eine „for“-Schleife vorstellen, die über eine oder mehrere Bilder und Lenkungsdaten iteriert und Vorhersagen macht. Am Ende des Stapels werden die Vorhersagen mit den erwarteten Ausgangsvariablen verglichen und ein Fehler wird berechnet. Anhand dieses Fehlers wird der Aktualisierungsalgorithmus verwendet, um das Modell zu verbessern.

Beim Trainieren wurden „Batches“ in Größe von 100 zufällig ausgewählten Daten aus dem Datensatz programmiert. Diese 100 Daten werden dann augmentiert und mit einem Farbenfilter auch Verarbeitet. Nach dem Prozess gibt die Funktion dataGen() einen y wert zurück, der von der model.fit() Funktion im Main Training Skript aufgerufen wird.

Die model.fit() Funktion ist eine Standardfunktion der Tensorflow Bibliothek zum Trainieren von Deep Learning Modelle. Hier werden die Ausgabewerte aus der dataGen() Funktion für die 80% Trainingsdatensätze der ganzen Daten und der 20% Validierungsdatensätze aufgerufen. Andere Inputs der model.fit() brauch sind „Batch-Größe“ , „Epoch“-Anzahl, und die Schritte pro „Batch“ für die Validierung und Trainingsdaten.

„Epoch“-Anzahl gibt die Anzahl der Durchläufe des gesamten Trainingsdatensatzes an, die der Algorithmus abschließen soll um das Modell fertig zu trainieren. Bei diesem Modell wurden 10 „Epoch‘s“ verwendet mit jeweils 100 „Batches“. Anders gesagt, haben wir 10 Schritte zum Trainieren des Modells und jeder Schritt hat 100 zufällig ausgewählte Daten, die jeweils 100-mal trainiert werden um einen „Epoch“ abzuschließen.

In Abb18. befindet sich ein Auszug aus dem trainierten Modell, wo man die Durchläufe beim Training ansehen kann. Um den Trainingsprozess im Anschluss zu visualisieren, wird das Training durch die Funktion model.fit() an eine Variable gespeichert.

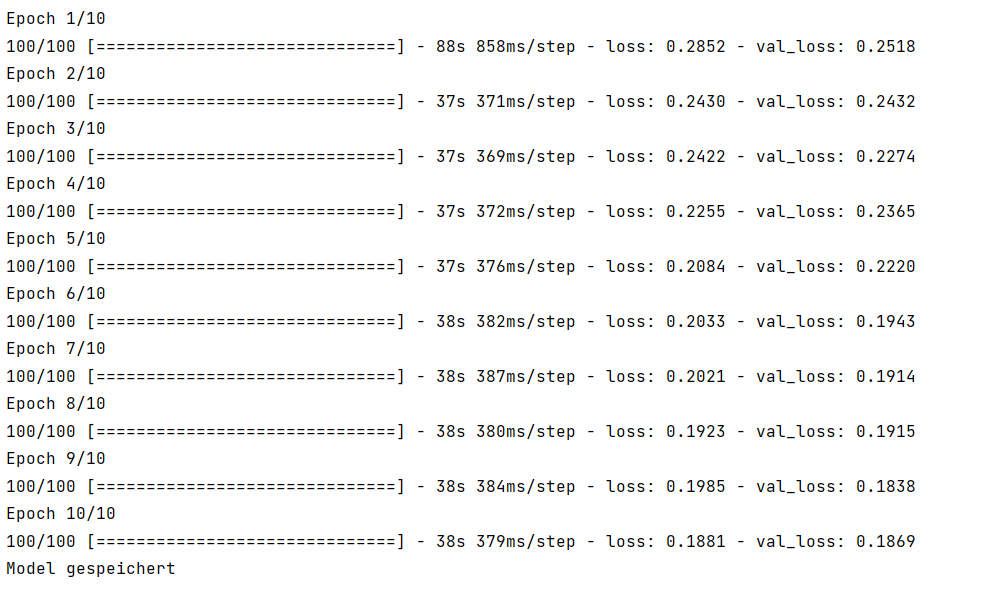
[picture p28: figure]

Abbildung 31: Trainieren des Models

9- Speichern des Models und Plotten der Ergebnisse

Nach dem das Training abgeschlossen ist, wird das Model gespeichert. Dies ist dann das endgültige Deep Learning Model mit dem der Omega-Tron autonom eine Fahrspur fahren kann.

Wie im oberen Abschnitt erwähnt, das Trainings Model wurde an eine Variable gespeichert. Dadurch kann man den Trainingsprozess visualisieren, um eine Aussage über die Effizienz des Modells zu treffen. Wie man in Abb.19 Erkennen kann, nimmt der Trainingsverlust mit zunehmender Anzahl von „Epoch’s“, d.h. mit zunehmender Anzahl von Trainingsdaten weiter ab.

Die Grafik der Validierungsverluste nimmt bis zu einem Punkt ab und beginnt dann wieder zu steigen und nach einer Weile sinkt die wieder ab. Der Wendepunkt im Validierungsverlust kann der Punkt sein, an dem das Training abgebrochen wird, da die Erfahrung nach diesem Punkt, die Dynamik der Überanpassung (Eng. „Overfitting“) zeigt.

Alles in allem kann man herauslassen, dass das trainierte Modell ein gutes Modell ist. Diese Stellungnahme kann man mit den folgenden zwei Gründen belegen:

- Die Kurve der Trainingsverluste sinkt bis zu einem Punkt der Stabilität ab
- Die Kurve der Validierungsverluste sinkt bis zu einem Punkt der Stabilität und hat einen kleinen Abstand zu den Trainingsverlusten, was bedeutet, dass das Modell nicht „Overfitted“ wurde.

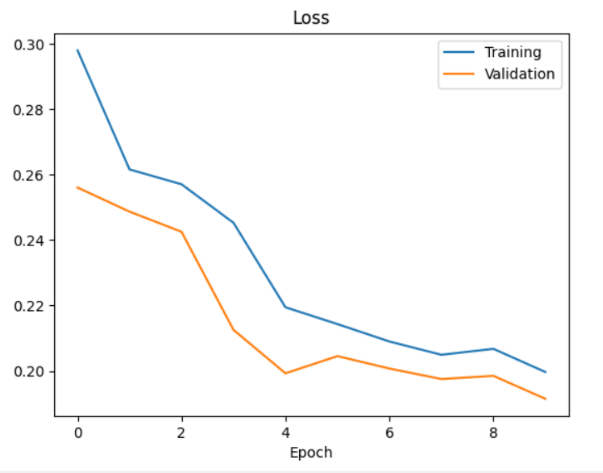
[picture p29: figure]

Abbildung 32: Ergebnisse aus der Training des Models

3.2.2.3 Umsetzung der CNN Model

Beim Umsetzen des CNN-Models wurde das Main Skript Omega_Tron_CNN_Main.py geschrieben. In diesem Skript wird das trainierte Model zusammen mit Kamera Modul und den Motormodul aufgerufen. Hier wird wiederum eine variable für die Sensitivität bei der Lenkung der Kurven sowohl als auch eine Maximale Geschwindigkeit, sodass die kurven Optimal aufgenommen werden können. Im Skript wird noch eine kleine Bildverarbeitungsfunktion geschrieben in dem alle von der Kamera Aufgenommenen Bilder pro Sekunde Augmentiert werden. Diese Augmentierte bilder werden an das Modell gesendet, die danach an den Motormodul befehle über die Lenkungsstärke übergibt. Diese Lenkungsstärke wird dann mit die definierten variablen für die Sensitivität und Geschwindigkeit Multipliziert.

3.2.3 Objekterkennung und Schnittstelle zu Roboterarm

3.2.3.1 Daten Sammlung und Training mit Yolo

Zur Bilderkennung nutzen wir ebenso die Raspberry Kamera, welche in Echtzeit Müll erkennen kann. Wie bereits in Kapitel 2.2.3. beschrieben, nutzen wir für die Erkennung Yolov3. Doch bevor es zur Modellbildung kommt, werden zuvor Daten benötigt:

1. Rohdaten sammeln: Damit später genau die Gegenstände erkannt werden, die zuvor festgelegt worden sind, müssen entsprechende Bilder ins System eingespeist werden. Dabei
nutzen | wir | öffentliche | Bilder | im | Internet, | als | auch | selbst | geschossene:
2. Daten aufbereiten: Nach etwa 1000 Bilder mit 4 verschiedenen Klassen (Bio, Papier, Schachtel, Dose) werden nun die Daten für das Modell vorbereitet. Mithilfe der Seite roboflow.ai können folgende Schritte durchgeführt werden:
a. Bild Labelling: Zunächst werden alle Bilder beschriftet. Dabei
legt man die Bounding Box um das Objekt und verseht diesen
noch mit der entsprechenden Bezeichnung.
b. Preprocessing: Hier wird das Bild auf 416x416 Pixel skaliert, was die Standardgröße bei Yolo ist. Dadurch kann Rechenzeit gespart werden.
c. Argumentation: Um den Trainingseffekt zu verbessern vermehren wir die Daten, indem wir die Bilder jeweils spiegeln und rotieren. Unser Datenpaket wurde somit verdreifacht.

Abbildung 33: Öffentliches Bild (links) und selbst geschossenes Bild (rechts)

Abbildung 34: Dose mit
Bounding Box

3. Daten ins Modell einspeisen: Dem vortrainierten Modell, welches ausführlich in Kapitel 2.2.3. beschrieben wurde, füttern wir mit unseren Daten ein. Der gesamte Ablauf findet über Google Colab statt und wird im Kapitel 6.4.5. beschrieben.
4. Training: Nachdem das Modell konfiguriert wurde, startet das Training. Je mehr Zyklen durchlaufen werden, desto mehr passt sich das Modell den Daten an:

Abbildung 35: x = Anzahl Zyklen, y = Prozentualer Fehler

3.2.3.2 Schnittstelle Yolo zu Roboterarm

Bei der Objekterkennung wird über die Yolo Bibliotheken der Programmcode Obj_Detection.py geschrieben, indem das trainierte Modell und die Klassennamendatei alle Abfallkategorien aufgerufen werden. In dem Code wird eine Funktion definiert als Objekt_Erkennung(), indem beim Erkennen einer Abfallkategorie eine „Bounding Box“ um das Objekt gelegt wird. Diese „Bounding Box“ ist ein virtuelles Rechteck, das als Bezugspunkt für die Objekterkennung dient und einen Rahmen für dieses Objekt bildet. Die wird über die OpenCV Bibliothek berechnet, sodass nur das erkannte Objekt umrandet wird. Über diesem Rahmen wird außerdem der Kategorienname und der Wahrscheinlichkeitswert, dass das Objekt zu der Kategorie gehört. Die Kategoriennamen sind in der Klassennamen Datei wie folgt gelistet:

[ | Bio_Müll; | Metllische_Dose; | Papier; | Karton_Schachtel; | Plastik | ]

Über die Python Bibliothek Numpy wird diese Liste als ein Array erkannt, indem der erste Listenname den Wert Null hat und das letzte den Wert Vier. Über diese Arraywerte werden anschließend die Kategorienamen beim Erkennen eines Objektes gelesen und über die „Bounding Box“ geschrieben.

Nachdem ein Objekt erkannt wird, wird die Funktion im Roboterarmcode aufgerufen und die einzelnen Schritte zur Abfallentsorgung durchgeführt. Nach der Erkennung eines Objektes wird der Klassenname des erkannten Objektes aufgerufen und es wird ausgegeben. Danach geht der Roboterarm in seine Ausgangs- bzw. Startposition. Sobald der Roboterarm beginnt nach dem Objekt zu greifen, wird ausgegeben, dass das Objekt gegriffen wird. Zum Schluss entsorgt der Roboterarm den Müll und dies wird als Print-Befehl ausgebeben, dass der Abfall entsorgt wurde.

### 3.3 Modulare Umsetzung und Kommunikation im Gesamtsystem

Gezeigt ist sowohl Leistungs- als auch Datenverbindungen des Roboter-Gesamtsystems zum aktuellen Ausbaustand. Die Abbildung ist nur eine qualitative Darstellung.

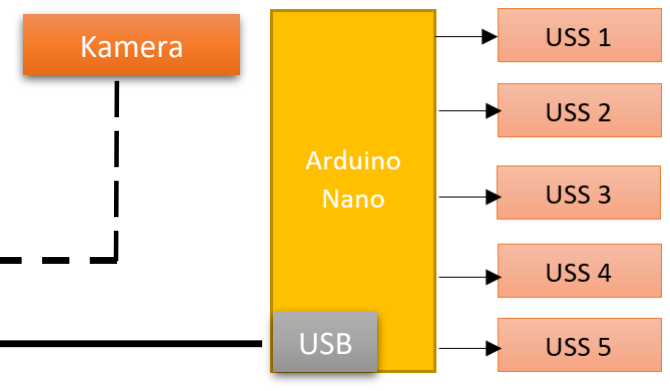
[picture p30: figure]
Kamera

Raspberry Pi

Lade
Platine

Powerbank

+ -

Servo 1

Akku

Servo Shield

Servo 2 | Servo 3 | Servo 4

Batt.

Roboterarm

USB | USB

Daten

GND

VCC

Anschluss
zu
Stromnetz

### 3.4 Konstruktion von Fehlenden Bauteilen

Im Laufe des Projektes M4000 kam es immer wieder vor, dass gewisse Bauteile für gewisse Elemente benötigt wurden. Da der Roboter ein für sich einzigartiges Gesamtsystem ist, waren die benötigten Dinge nicht einfach zu kaufen oder zu bestellen. Aus diesem Grund wurde zur Maßnahme des 3D-Druckens gegriffen und viele Teile selbstständig mit Solid Edge konstruiert und ausgedruckt. Auch haben gewisse Teile in Bestellungen gefehlt, wodurch diese ersetzt werden mussten.

Zunächst musste eine Karosserieebene beschafft werden, da der Roboter, vor allem aufgrund der Verkabelung und der Recheneinheiten, sich auf drei Ebenen verlaufen werden sollte. Hierbei haben wir uns an der mitgelieferten Ebene des Fahrzeuggestells orientiert und diese in einem etwas größeren Maße reproduziert.

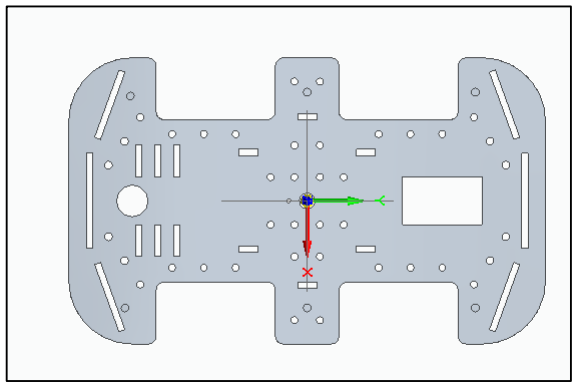
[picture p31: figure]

Abbildung 36: Karosserie Ebene für den Modellroboter

Insbesondere für die Sensorik und Kamera wurden Halterungen konstruiert, damit diese sicher und fest auf dem Roboter angebracht werden konnten. Hierbei war es wichtig, dass die Teile nicht viel Platz einnehmen, jedoch auch nicht zerbrechlich oder zu leicht sind. Auch war die Funktionalität eine sehr wichtige Komponente bei der Konstruktion dieser Teile. Die Funktion des Bauteils für welches ein Teil konstruiert und gedruckt wurde, musste in erster Linie nicht beeinträchtigt werden. Jedoch wurde auch auf die Optik und auf den Look der Teile geachtet, da diese indirekt den Roboter repräsentieren.

Abbildung 37: Links: USS-Halter, rechts oben: Kamerahalter, Rechtsunten: Kamerahalter mit IR-Sensoren

Für den Roboterarm musste auch ein Teil konstruiert werden, da dieses Teil in der Bestellung gefehlt hat. Hierbei musste man insbesondere darauf achten, dass das Bauteil den Kräften und Momenten des

Roboterarms und der Servomotoren standhalten kann. Wie auch oben erwähnt war die Funktionalität hier an erster Stelle. Des Weiteren musste ein Stützbein für die konstruierte Ebene angefertigt werden. Hierbei ist auch sehr gut die Individualität des Roboters zu sehen, da hier für ein selbstständig konstruiertes Teil ein weiteres selbstständig konstruiertes Teil angefertigt wurde.

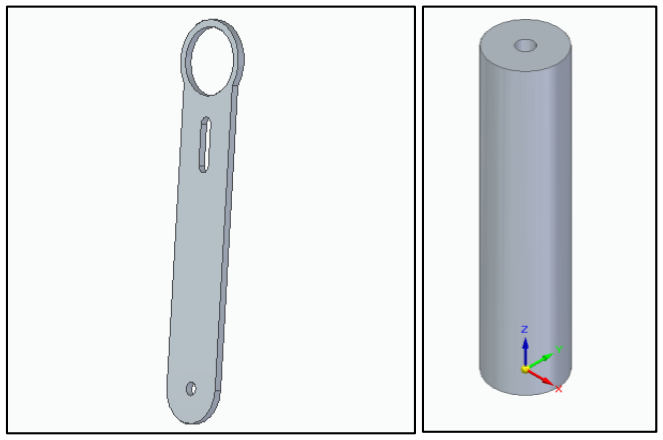
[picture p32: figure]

Abbildung 38: Links: Fehlende Bauteil für den Roboterarm, Rechts: Stützbeine für die Konstruierte Ebene

Zu guter Letzt wurde ein Logo für den Omega-Tron konstruiert und ausgedruckt, da dieser ein Zeichen für die gemachte Arbeit und als Aushängeschild des Roboter dient.

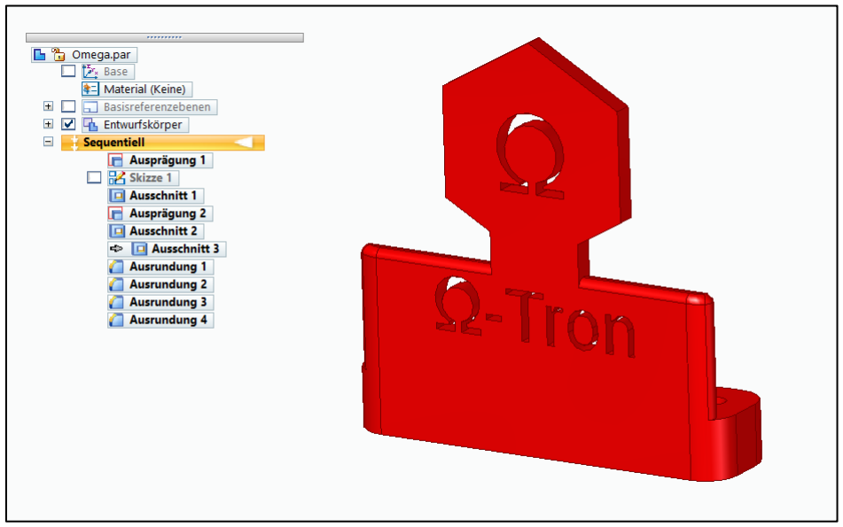
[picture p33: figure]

Abbildung 39: 3D-Gedruckte Logo von Omega-Tron

### 4 Probleme bei Umsetzung und deren Behebung

### 4.1 Fahrspurerkennung

4.1.1 Bildverarbeitung

Im Kapitel 2.2.1.1 Bildverarbeitung wurden zwei verschiedene Algorithmen zur Fahrspurerkennung vorgeschlagen. Nach mehreren Probeläufen gab es bei dem ersten Algorithmus einige Komplikationen bei der Kurvenerkennung. Die Erkennung von geraden Fahrspurlinien war hier kein Problem, jedoch war es problematisch gekrümmte Linien zu erkennen.
Das Problem wurde durch das „Birdseyeview“ Methode gelöst. Durch das Einstellen des Bildes in die Draufsicht entspricht die Form einer Fahrspur nahezu der realen Fahrbahn mit einer minimalen Verzerrung. Durch diese Transformation kann man auch gekrümmten Fahrspurlinien erkennen.
Aus diesem Grund wird dieser Algorithmus auch bei Omega-Tron implementiert und hat zuverlässige Ergebnisse ergeben. Nach einigen Probeläufen und mehreren versuchen wurden die Optimalen Werte zum Einstellen des HSV-Bildes gefunden sowohl als auch die Optimale Geschwindigkeit und Sensitivität mit dem das Auto die Kurven aufnehmen kann. Dabei ist zu beachten, dass die Raspberry PI eine Framerate von ungefähr 14 fps hat, und die Geschwindigkeit beim Lenken soll auch entsprechend eingestellt werden damit das Auto nicht schneller als die bilder Verarbeitungsrate ist.

4.1.2 Deep Learning Model

Beim training des Deep Learning Models wurden mehrere Datensätze gesammelt, wobei einige von dem zu wenig Daten hatten oder eine „Overfitting“ Verhalten nach dem Trainieren gezeigt haben. Die Ergebnisse aus der im Omega-Tron Implementierten Model zeigen, dass es gut geeignet ist, um autonom durch eine Fahrbahn zu fahren. Das Modell könnte eventuell noch verbessert werden durch das zufügen von mehr Trainingsdaten. Jedoch ist das „Overfitting“ Problem zu beachten

Abbildung 40: Ergebnisse des trainierten CNN-Model

Beim Implementieren des Modells gab es jedoch ein Problem beim Herunterladen der Tensorflow-Bibliothek in Raspberry Pi. Die könnte nicht richtig heruntergeladen werden da es einige Komplikationen zwischen den PIP Bibliothek, den aktuellen Python 3 Version und numpy in Raspberry gab. Das Herunterladen einer älteren Version von Tensorflow oder das Herunterladen von Tensorflow Lite hat das Problem auch nicht gelöst.

Das Installieren der Raspbian Betriebssystem oder von einem Ubuntu Version in einen anderen SD-Karte ist eine gute Lösungsansatz um mögliche defekte Bibliotheken Pakete zu aktualisieren.

### 4.2 Objekterkennung

Die Objekterkennung funktioniert zuverlässig bei der Erkennung von den fünf trainierten Kategorien und kann auch problemlos mit dem Roboterarm interagieren. Die Bildverarbeitung seitens Raspberry Pi ist etwas langsam, was dazu führt, dass erkannte Objekte nicht in Echtzeit dargestellt werden können. Trotz dieses Problems ist dies kein Hindernis für das zuverlässige Erkennen und Greifen von Objekten.

Abbildung 41: Objekterkennung mit Yolo

### 4.3 Roboterarm

Beim Roboterarm gab es von Anfang an insbesondere mechanische und Hardwaretechnische Probleme.

Nachdem das Paket mit den Teilen für den Roboterarm angekommen ist, ist sofort aufgefallen, dass gewisse Bauteile, welche von immenser Bedeutung für die Funktionalität des Greifers sind, fehlen, sodass diese zunächst einmal nachkonstruiert und anschließend 3D gedruckt werden mussten. Trotz sorgfältigem und sauberem Arbeiten ist das Ersatzteil auf Grund des Materials des 3D Druckers nicht auf das gleiche qualitative Niveau des Originalteils zu stellen.

Ein weiteres Problem war, dass der Servotreiber der bestellt wurde, keine Verbindung zum Raspberry Pi herstellen konnte, wodurch ein Ersatzteil beschafft werden musste. Hierbei wurde man glücklicherweise Elektro-Labor des C-Labs fündig und konnte dieses Problem, ohne zu sehr Zeit zu verlieren beseitigen.

Das größte Problem beim Roboterarm war die Spannungsversorgung. Hierbei war vorausgesetzt, dass die Servomotoren eine Spannung von 5V und einen Strom von 1 A benötigen. Die Batterien, an denen der Roboterarm angeschlossen war, haben diese Versorgung ohne Probleme zunächst aufgewiesen. Jedoch hat man nach einer sehr kurzen Zeit schon gesehen, dass die Servomotoren nicht mehr die Leistung aufbringen können, welche notwendig war, um die Gelenke zu bewegen. Als die Batterien gemessen wurden, hat man einen starken Spannungsabfall messen können. Auch beim zweiten Versuch und mit frischen Batterien ist dieses Problem nicht beseitigt werden können. Zu Testzwecken wurde ein vom Lieferanten mitgeliefertes Netzteil verwendet. Schließlich wurde dazu entschieden den Roboterarm mit einer Powerbank zu betreiben, da hier der Spannungsabfall nicht bemerkbar war.

### 4.4 Hindernisumfahrung

Die Ultraschallsensoren funktionieren problemlos, wenn die einzeln betrieben werden. Bei der Verwendung aller Sensoren, werden die Trigger von einzelnen Sensoren von allen Sensoren gemessen. Dies führt zu einer Fehlinterpretation der Entfernungen in der jeweiligen Richtung. Dadurch kommt es zu Fehlerhafte Entfernungsmessung.

Durch ein Vereinzeln der Messungen kann das Problem umgangen werden. Jedoch führt das zu einen geringeren Abtastrate der Entfernungsmessung.

### 4.5 Motorsteuerung

Bei der Verwendung von AMSpi ist beim schrieben des Motortreibers das Problem entstanden, dass ein GPIO cleanup nach den Funktionsaufrufen stattfand, dadurch wurden die Motoren faktisch nicht angesteuert. Eine andre Programmstruktur löste diesen Fehler. Bei der Handsteuerung fiel das Problem auf, dass der Roboter ohne Ansteuerung den letzten Fahrbefehl beibehielt. Dies wurde durch einen nach einem Timer gesteuerten Stopp Befehl gelöst.

### 4.6 Ortung und Navigation

Bei der Installation von ROS/ dessen Module stellte sich das Betriebssystem Raspbian leider als nicht überwindbares Hindernis heraus. Für eine erfolgreiche Implementierung muss der Roboter am besten auf Ubuntu Mate umgestellt werden. Dafür benötigt man dort einen Workaround zum Verwenden der GPIO’ s.

### 4.7 Induktives Laden

Beim Bestellen wurde die Station vergessen. Deswegen und auf Grund der mangelnden Navigationsfähigkeit, haben wir uns dazu entschlossen, die Zielsetzung hintenanzustellen. Bis auf die Ladestation ist die IMU und die Ladespule aber physisch vorhanden nur aufgrund des fehlenden Nutzens noch nicht angeschlossen. Die Ladezustandsmessung benötigt noch eine Verstärkerschaltung um die 200mV auf die zum Messen benötigten 3V zu verstärken.

### 5 Zusammenfassung und Ausblick

Alles in allem verfügt Omega-Tron über ein hohes Maß an Zuverlässigkeit bei der Durchführung der Aufgaben für die einzelnen Module, die Motorsteuerung, die Steuerung des Roboterarms, Fahrspurerkennung und Objekterkennung.

Außerdem besteht ein hohes Potential an Verbesserungen der jeweiligen Module durch Erweiterung und Weiterentwicklung. Beispielsweise das Einbauen einer TPU (Tensor Processing Unit) würde den Prozess beim autonomen Fahren und bei der Objekterkennung deutlich verbessern, womit der Raspberry Pi die betreffenden Module schneller ausführen würde.

Aktuell erkennt der Roboter den vor ihm liegenden Abfall, wodurch der Greifarm-Befehl automatisch zum Einsatz kommt. Eine Verbesserung, die auch bereits in der Praxis Anwendung findet, ist, dass der Roboter entlang des fahrenden Weges Abfall von weiterer Entfernung erkennt und gezielt dorthin fährt. Dies ist durch das Hinzufügen von Modulen im Hauptskript und das Aufrufen vom Motor- und USS-Modul realisierbar. Durch das Trainieren von größeren Datensätzen, kann die Klassifizierungsgenauigkeit erhöht werden.

Bei der Wahrnehmung der Umgebung, um eine Datenkollision zu verhindern, welches durch Interferenz der USS zur Stande kommt, wäre es besser die einzelnen Entfernungsmessung mit zeitlich größerem Abstand zu legen.

Während dem Projekt sind die Komplexität und der Umfang eines solchen Modellroboterprojektes jedem von uns sehr deutlich aufgezeigt worden, was Motivation und Anreiz schaffte, um die inneren Prozesse bei autonom fahrendem Roboter zu erlernen und die theoretischen Grundlagen in diesem Bereich zu vertiefen.

Zum Abschluss möchten wir uns an das gesamte C-Lab für die Werkzeug-, als auch Materialbereitstellung bedanken. Außerdem war durch die Bereitstellung Ihrer Räumlichkeiten stets ein produktives Arbeiten möglich.

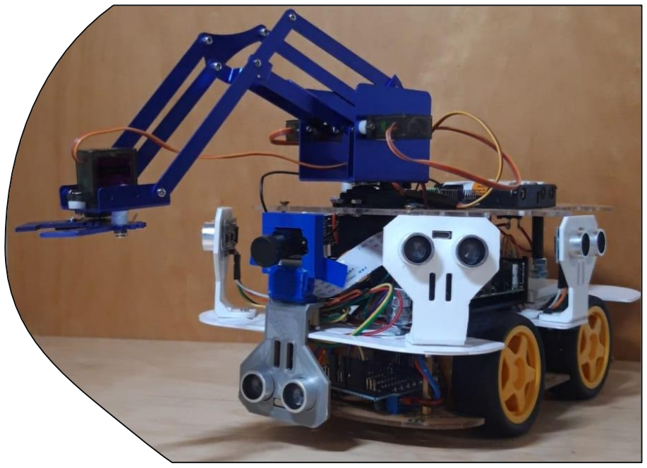
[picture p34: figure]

Abbildung 42: Omega-Tron

### 6 Anhang

### 6.1 Anforderungsliste 6.2 Projektplan 6.3 Bestellliste 6.4 Programcode

6.4.1 Motorsteuerung
6.4.2 Hindernisumfahrung
6.4.3 Fahrspurerkennung
6.4.4 Objekterkennung
6.4.5 Roboterarm

### Abbildungsverzeichnis

Abbildung 22: Koordinaten der Aktuellen Bild (Links) und mit Transformierte Koordinaten in HSV-

Abbildung 37: Links: USS-Halter, rechts oben: Kamerahalter, Rechtsunten: Kamerahalter mit IR-

Abbildung 38: Links: Fehlende Bauteil für den Roboterarm, Rechts: Stützbeine für die Konstruierte

### Literaturverzeichnis

Fahrspurerkennung

https://easychair.org/publications/preprint_download/4DRl

https://towardsdatascience.com/a-deep-dive-into-lane-detection-with-hough-transform-8f90fdd1322f (https://towardsdatascience.com/a-deep-dive-into-lane-detection-with-hough-transform-8f90fdd1322f)

https://towardsdatascience.com/deeppicar-part-1-102e03c83f2c

https://towardsdatascience.com/deeppicar-part-4-lane-following-via-opencv-737dd9e47c96

https://github.com/TurtleTaco/Advanced-Lane-Detection

http://www.gm.fh-koeln.de/~hk/lehre/ala/ws0506/Praktikum/Projekt/E_rot/Dokumentation.pdf

https://www.hindawi.com/journals/js/2016/4058093/

https://sbme-tutorials.github.io/2019/cv/notes/4_week4.html

https://github.com/naokishibuya/car-finding-lane-lines

https://www.researchgate.net/figure/Lane-detection-with-Hough-transform-performed-using-OpenCV_fig3_332897463 (https://www.researchgate.net/figure/Lane-detection-with-Hough-transform-performed-using-OpenCV_fig3_332897463)

http://coecsl.ece.illinois.edu/ge423/spring05/group8/FinalProject/HSV_writeup.pdf

https://www.opencv-srf.com/2010/09/object-detection-using-color-seperation.html

https://stackoverflow.com/questions/22588146/tracking-white-color-using-python-opencv

https://en.wikipedia.org/wiki/HSL_and_HSV

https://www.computervision.zone/courses/self-driving-car-using-raspberry-pi/

https://wiki.hshl.de/wiki/index.php/Kamerabildtransformation_in_Vogelperpektive

https://projects-raspberry.com/curved-lane-detection/

https://github.com/yukitsuji/Advanced_Lane_Finding

https://www.youtube.com/watch?v=PZsbROEpfNU

https://www.hindawi.com/journals/js/2016/4058093/

https://stackoverflow.com/questions/43226702/image-warping-using-opencv

https://medium.com/analytics-vidhya/opencv-perspective-transformation-9edffefb2143

https://theailearner.com/tag/cv2-getperspectivetransform/

https://www.geeksforgeeks.org/perspective-transformation-python-opencv/

https://www.programcreek.com/python/example/85017/cv2.getPerspectiveTransform

https://manivannan-ai.medium.com/set-trackbar-on-image-using-opencv-python-58c57fbee1eehttps://stackoverflow.com/questions/39362497/how-can-i-set-the-default-positio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 (https://stackoverflow.com/questions/39362497/how-can-i-set-the-default-position-of-a-trackbar-in-opencv)

https://www.programcreek.com/python/example/70426/cv2.createTrackbar

https://www.programcreek.com/python/example/70423/cv2.getTrackbarPos

Deep Learning und Convolutional Neural Networks

https://news.microsoft.com/de-de/microsoft-erklaert-was-ist-deep-learning-definition-funktionen-von-dl/ (https://news.microsoft.com/de-de/microsoft-erklaert-was-ist-deep-learning-definition-funktionen-von-dl/)

https://www.kaggle.com/ryanholbrook/a-single-neuron

https://towardsdatascience.com/deeppicar-part-5-lane-following-via-deep-learning-d93acdce6110

https://github.com/PacktPublishing/Applied-Deep-Learning-and-Computer-Vision-for-Self-Driving-Cars (https://github.com/PacktPublishing/Applied-Deep-Learning-and-Computer-Vision-for-Self-Driving-Cars)

https://towardsdatascience.com/deeppicar-part-5-lane-following-via-deep-learning-d93acdce6110

https://developer.nvidia.com/drive/drive-perception

Nvidia model
https://developer.nvidia.com/blog/deep-learning-self-driving-cars/

https://images.nvidia.com/content/tegra/automotive/images/2016/solutions/pdf/end-to-end-dl-using-px.pdf (https://images.nvidia.com/content/tegra/automotive/images/2016/solutions/pdf/end-to-end-dl-using-px.pdf)

https://github.com/tbchhetri/selfDrivingCar

https://github.com/shawpan/drive

Objekterkennung

https://www.matse.itc.rwth-aachen.de/dienste/public/show_document.php?id=1875

https://www.youtube.com/watch?v=F5KpG7fcYaY

https://jonathan-hui.medium.com/real-time-object-detection-with-yolo-yolov2-28b1b93e2088

Abb.9: https://blog.330ohms.com/2020/11/17/deteccion-de-objetos-con-yolo/

Abb21: https://www.flickr.com/photos/30478819@N08/50635298728

### Abkürzungsverzeichnis

ACC | Adaptive Cruise Control
CNN | Convolutional Neural Network
Eng. | Englisch (Hier englische Fachbegriff)
HSV | Hue/Saturation/Value Farbenspektrum
LKAS | Lane Keep Assistance System
RGB | Red/Blue/Green Farbenspektrum
USS | Ultraschall Sensor

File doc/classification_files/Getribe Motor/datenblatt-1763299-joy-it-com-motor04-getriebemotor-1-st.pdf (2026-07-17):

3

# Getriebemotor


Veröffentlicht: 06.12.2018 | Time for more | www.joy-it.net

### Technische Daten

Modell | Getriebemotor
Artikelnummer | Com-Motor04
Spannungsversorgung | 3-9V DC
Umdrehungen pro Minute | Ca. 190 UPM bei 6V
Motorgröße | Ca. 12 x 24mm
Raddurchmesser | Ca. 67mm
Abmessungen (Motor) | 45 x 42mm
Lieferumfang | Motor, Rad
EAN | 4250236817248

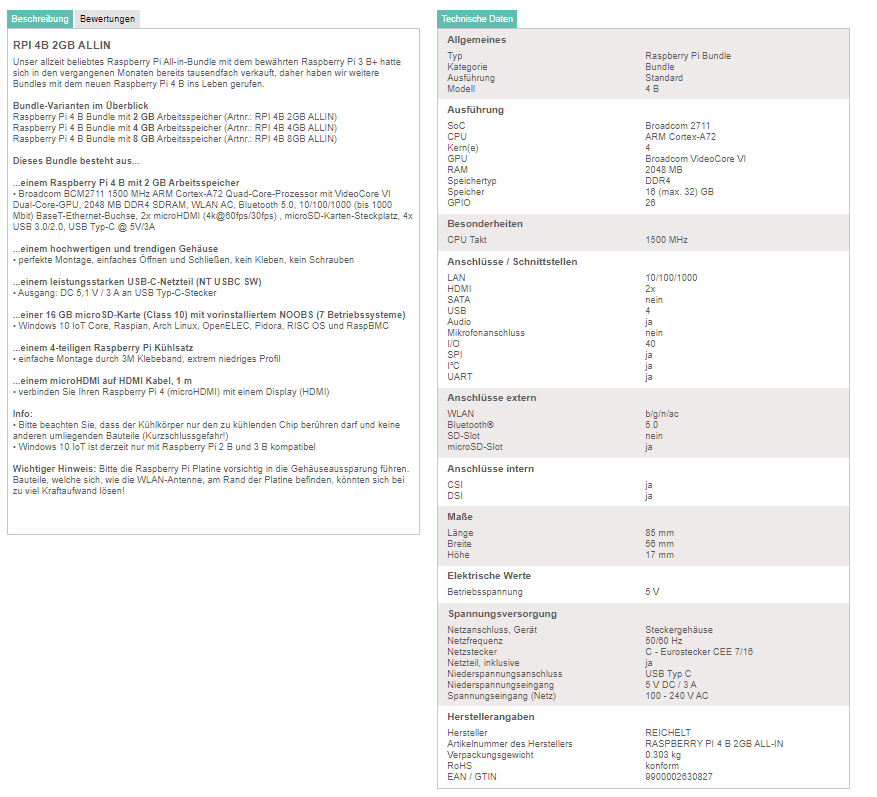
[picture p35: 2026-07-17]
doc/classification_files/Rasberry Pi/R_Pi.png

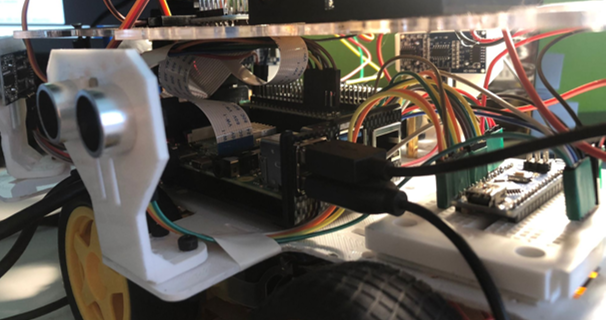
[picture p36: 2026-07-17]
doc/vids_pics/DistanceSensors1.png

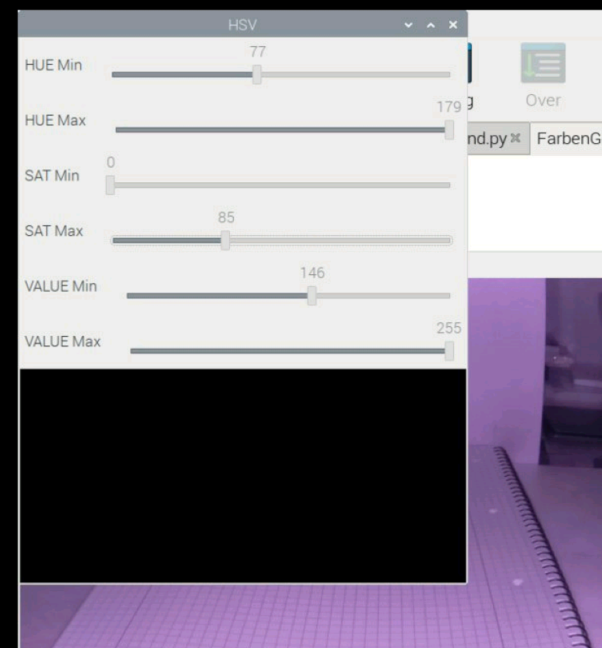
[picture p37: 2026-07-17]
doc/vids_pics/opencv3.png

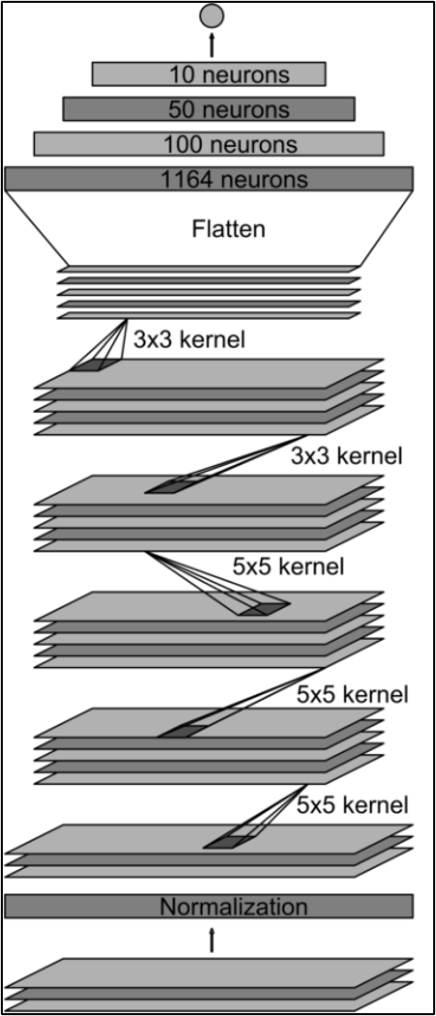
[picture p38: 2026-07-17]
doc/vids_pics/LaneDetection6.png

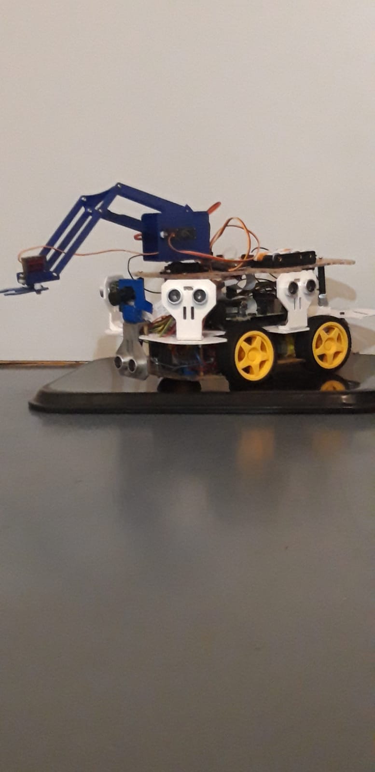
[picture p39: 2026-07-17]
doc/vids_pics/OmegaTron2.jpeg

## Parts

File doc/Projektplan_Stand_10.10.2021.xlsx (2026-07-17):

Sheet: Anforderungsliste
Anforderungsliste
Projektname: Omega-Tron
Pos | F/W | Anforderung für Aufgabe / Teilaufgabe | Wert | Einheit
1. |  | Gesamtsystem
1.1. | F | Herstellkosten | <400 | €
1.2. | F | Mobilität
1.3. | W | Transportabel
1.4. | W | Komplett autonom
1.5. | W | Schickes Design
1.6. | W | Zerlegbarkeit
2. |  | Roboterauto
2.1. | F | Vorwärts-/Rückwärts-/Lenkbewegung
2.2. | F | Fahrspurverfolgung
2.3. | F | Hindernisumfahrung
2.4. | F | Objekterkennug
2.5. | F | Roboterarm Ausführung
2.6. | W | Akkustandsanzeige
2.7. | W | Standortbestimmung
2.8. | W | Selbständige Rückkehr zur Station bei kritischem Akkustand
2.9. | W | Aktiver Parkassistent
3. |  | ,,
3.1. | F | Über Computer
3.2. | W | Über Smartphone
4. |  | Ladestation
4.1. | W | Wireless Charging
4.2. | W | Gehäuse/Garage
5. |  | Schnittstelle Ladestation-Roboterauto
5.1. | F | Energiefluss möglich
5.2. | W | Parkschild (QR-Code) Erkennung
6. |  | Schnittstelle Roboterauto-Bedienung
6.1. | W | Fahrzeug selbst steuern
6.2. | W | Roboterarm manuell bedienen

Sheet: Projektplan
Projektplan
Projekt |  |  | Omega-Tron |  |  |  |  |  |  | Farbspiegel
Projektnummer |  |  | k. A. |  |  |  |  |  |  | geplant
Projektleiter/in |  |  | k. A. |  |  |  |  |  |  | abgeschlossen
Datum |  |  | 2021-03-29 |  |  |  |  |  |  | Meilenstein
Projekteilnehmer |  |  | Çurumi, Arlind Häußler, Christoph Qiu, Jiang Qi Güney, Ismail
Stand: |  | 2021-10-10 |  |  |  |  |  |  |  | Monat | April 21 |  |  |  |  |  |  | April 21 |  |  |  |  |  |  | April 21 |  |  |  |  |  |  | April 21 |  |  |  |  |  |  | April 21 |  |  |  |  |  |  | May 21 |  |  |  |  |  |  | May 21
 |  |  |  |  | Kalenderstart | 2021-03-29 |  |  |  | KW | 13 |  |  |  |  |  |  | 14 |  |  |  |  |  |  | 15 |  |  |  |  |  |  | 16 |  |  |  |  |  |  | 17 |  |  |  |  |  |  | 18 |  |  |  |  |  |  | 19
 |  |  |  |  | Nur Arbeitstage (x=Ja) |  |  |  |  | Tageszähler | 1 | 2 | 3 | 4 | 5 | 6 | 7 | 8 | 9 | 10 | 11 | 12 | 13 | 14 | 15 | 16 | 17 | 18 | 19 | 20 | 21 | 22 | 23 | 24 | 25 | 26 | 27 | 28 | 29 | 30 | 31 | 32 | 33 | 34 | 35 | 36 | 37 | 38 | 39 | 40 | 41 | 42 | 43 | 44 | 45 | 46 | 47 | 48
 |  |  |  |  |  |  |  |  |  | Wochentag | Mon | Tue | Wed | Thu | Fri | Sat | Sun | Mon | Tue | Wed | Thu | Fri | Sat | Sun | Mon | Tue | Wed | Thu | Fri | Sat | Sun | Mon | Tue | Wed | Thu | Fri | Sat | Sun | Mon | Tue | Wed | Thu | Fri | Sat | Sun | Mon | Tue | Wed | Thu | Fri | Sat | Sun | Mon | Tue | Wed | Thu | Fri | Sat
 |  |  |  |  |  |  |  |  |  | Datum | 2021-03-29 | 2021-03-30 | 2021-03-31 | 2021-04-01 | 2021-04-02 | 2021-04-03 | 2021-04-04 | 2021-04-05 | 2021-04-06 | 2021-04-07 | 2021-04-08 | 2021-04-09 | 2021-04-10 | 2021-04-11 | 2021-04-12 | 2021-04-13 | 2021-04-14 | 2021-04-15 | 2021-04-16 | 2021-04-17 | 2021-04-18 | 2021-04-19 | 2021-04-20 | 2021-04-21 | 2021-04-22 | 2021-04-23 | 2021-04-24 | 2021-04-25 | 2021-04-26 | 2021-04-27 | 2021-04-28 | 2021-04-29 | 2021-04-30 | 2021-05-01 | 2021-05-02 | 2021-05-03 | 2021-05-04 | 2021-05-05 | 2021-05-06 | 2021-05-07 | 2021-05-08 | 2021-05-09 | 2021-05-10 | 2021-05-11 | 2021-05-12 | 2021-05-13 | 2021-05-14 | 2021-05-15
Pos. | Linie zeigen | Aufgabe/Tätigkeit | Beginn [Datum] | Endet nach [Tagen] | Ende [Datum] keine Eingabe | Status [0 bis 100] | Meilenstein [Datum] | F | Verantwortlich [Name] | Unterstützung [Name]
1 | x | Planungsphase | 2021-03-29 | 21 | 2021-04-18 | 100% |  | F
2 |  | Ideensammlung | 2021-03-29 | 7 | 2021-04-04 | 100% |  |  | Alle | -
3 |  | Abwägung | 2021-04-05 | 3 | 2021-04-07 | 100% |  |  | Alle | -
4 |  | Kostenschätzung | 2021-04-08 | 4 | 2021-04-11 | 100% |  |  | Qiu | -
5 |  | Projektplanung | 2021-04-12 | 7 | 2021-04-18 | 100% |  |  | Çurumi | -
6 | x | Konzeptphase | 2021-04-19 | 43 | 2021-05-31 | 100% |  | F
7 |  | Zielsetzung | 2021-04-19 | 8 | 2021-04-26 | 100% |  |  | Alle | -
8 |  | Anforderungsliste | 2021-04-23 | 12 | 2021-05-04 | 100% |  |  | Qiu | -
9 |  | Lösungsansätze | 2021-04-27 | 18 | 2021-05-14 | 100% |  |  | Alle | -
10 |  | Bestellung Bauteile | 2021-05-01 | 5 | 2021-05-05 | 100% |  |  | Häußler, Qiu | Güney
11 | x | Schaltungskonzept Entwicklung | 2021-05-14 | 27 | 2021-06-09 | 100% |  | F
12 |  | Motorsteuerung Schaltkonzept | 2021-05-14 | 21 | 2021-06-03 | 100% |  |  | Häußler | Çurumi
13 |  | Hindernisumfahrung | 2021-05-16 | 5 | 2021-05-20 | 100% |  |  | Çurumi | Häußler
14 |  | Induktives Laden und Einparken | 2021-05-21 | 21 | 2021-06-10 | 100% |  |  | Häußler | -
15 |  | Schaltplan Roboterarm | 2021-05-28 | 5 | 2021-06-01 | 100% |  |  | Çurumi | -
16 | x | Fahrspurerkennung Konzeptentwicklung | 2021-07-23 | 62 | 2021-09-22 | 100% |  | F
17 |  | Algorhythmus Entwürfe | 2021-07-23 | 14 | 2021-08-05 | 100% |  |  | Çurumi | -
18 |  | Erprobung des Algorhythmus | 2021-08-08 | 6 | 2021-08-13 | 100% |  |  | Çurumi | -
19 |  | Diagnose und Debugging | 2021-07-29 | 21 | 2021-08-18 | 100%
20 |  | Konzeptauswahl | 2021-08-14 | 3 | 2021-08-16 | 100% |  |  | Çurumi | -
21 |  | Deep Learning Algorhythmusauswahl zur Data Training | 2021-08-20 | 10 | 2021-08-29 | 100% |  |  | Çurumi | -
22 |  | Data Collection | 2021-08-20 | 6 | 2021-08-25 | 100% |  |  | Çurumi | -
23 |  | Data Training | 2021-09-01 | 5 | 2021-09-05 | 100% |  |  | Çurumi | -
24 |  | Umsetzung und Erprobung der Algorhythums | 2021-09-10 | 14 | 2021-09-23 | 100% |  |  | Çurumi | -
25 | x | Objekterkennung Konzeptentwicklung | 2021-07-23 | 58 | 2021-09-18 | 100% |  | F
26 |  | Algorhythmus Entwürfe | 2021-07-25 | 9 | 2021-08-02 | 100% |  |  | Çurumi | -
27 |  | Erprobung des Algorhythmus | 2021-08-05 | 6 | 2021-08-10 | 100% |  |  | Çurumi | -
28 |  | Diagnose und Debugging | 2021-08-12 | 1 | 2021-08-12 | 100% |  |  | Çurumi | -
29 |  | Konzeptauswahl | 2021-07-28 | 18 | 2021-08-14 | 100% |  |  | Çurumi | -
30 |  | Deep Learning Algorhythmusauswahl zur Data Training | 2021-08-19 | 4 | 2021-08-22 | 100% |  |  | Çurumi | -
31 |  | Data Collection | 2021-08-10 | 11 | 2021-08-20 | 100% |  |  | Qiu | Çurumi
32 |  | Data Training | 2021-08-21 | 7 | 2021-08-27 | 100% |  |  | Qiu | -
33 |  | Umsetzung und Erprobung der Algorhythums | 2021-08-29 | 21 | 2021-09-18 | 100% |  |  | Çurumi | -
34 | x | Konzeptentwicklung autonomes Greifen mittels Objekterkennung | 2021-07-29 | 60 | 2021-09-26 |  |  | F
35 |  | Roboterarm Codeentwurf | 2021-07-29 | 11 | 2021-08-08 | 100% |  |  | Güney | -
36 |  | Schnittstelle Robotarm-Objekterkennung | 2021-08-16 | 28 | 2021-09-12 | 100% |  |  | Çurumi | -
37 |  | Umsetzung und Erprobung der Algorhythums | 2021-09-16 | 11 | 2021-09-26 | 100% |  |  | Çurumi | -
38 | x | Konzeptentwicklung Hindernissumfahrung | 2021-09-04 | 16 | 2021-09-19 |  |  | F
39 |  | Algorhythmus Entwurf | 2021-09-04 | 8 | 2021-09-11 | 100% |  |  | Çurumi | -
40 |  | Erprobung des Algorhythmus | 2021-09-11 | 3 | 2021-09-13 | 100% |  |  | Çurumi | Häußler
41 |  | Konzeptumsetzung und Diagnose | 2021-09-18 | 2 | 2021-09-19 | 100% |  |  | Çurumi | -
42 | x | Konzeptentwicklung Motorsteuerung und ROS | 2021-08-16 | 24 | 2021-09-08 |  |  | F
43 |  | Motorsteuerung Algorhythmus Entwurf | 2021-08-16 | 34 | 2021-09-18 | 100% |  |  | Häußler | -
44 |  | Erprobung der Algorithmus | 2021-09-16 | 11 | 2021-09-26 | 100% |  |  | Häußler | -
45 |  | ROS Konzeptentwurf | 2021-08-04 | 36 | 2021-09-08 | 100% |  |  | Häußler | -
46 |  | ROS Konzeptumsetzung |  |  |  |  |  |  | Häußler | -
47 | x | Konzeptentwicklung Induktives Laden und Einparken | 2021-08-09 | 12 | 2021-08-20 |  |  | F
48 |  | Algorithmus Entwurf | 2021-08-09 | 5 | 2021-08-13 | 100% |  |  | Häußler | -
49 |  | Erprobung des Algorhythmus | 2021-08-15 | 6 | 2021-08-20 |  |  |  | Häußler | -
50 | x | Konstruktion Fehlende Bauteile | 2021-06-16 | 65 | 2021-08-19 |  |  | F
51 |  | Bodenplatte für zusätzliche Ebene | 2021-06-16 | 4 | 2021-06-19 | 100% |  |  | Çurumi | -
52 |  | Halterung USS | 2021-06-17 | 6 | 2021-06-22 | 100% |  |  | Çurumi | -
53 |  | Halterung Kamera | 2021-06-17 | 2 | 2021-06-18 | 100% |  |  | Çurumi | -
54 |  | Logo Omega-Tron | 2021-09-28 | 1 | 2021-09-28 | 100% |  |  | Çurumi | -
55 |  | Ersatzbauteil Roboterarm | 2021-08-19 | 1 | 2021-08-19 | 100% |  |  | Çurumi | -
56 | x | Zussamenbau | 2021-09-29 | 2 | 2021-09-30 |  |  | F
57 |  | Karosserie mit Motorsteuerung und Induktive Ladung | 2021-09-29 | 2 | 2021-09-30 | 100% |  |  | Häußler | Çurumi
58 |  | Ultraschallsensoren und Kamera | 2021-09-30 | 1 | 2021-09-30 | 100% |  |  | Çurumi | Hußler
59 |  | Roboterarm | 2021-09-30 | 1 | 2021-09-30 | 100% |  |  | Çurumi | Güney
60 |  | Testung und Fehlerbehebung
61 | x | Dokumentation Vorbereitung | 2021-10-02 | 11 | 2021-10-12
62 |  | Dokumentation zu Projektarbeit | 2021-10-02 | 11 | 2021-10-12 | 100% |  |  | Alle | -
63 |  | PowerPoint Präsentation | 2021-10-03 | 10 | 2021-10-12 | 100% |  |  | Alle | -

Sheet: Stückliste
Strukturstückliste
Projektname: Omega-Tron
Position |  |  | Anz | Beschreibung | Position |  |  | Anz | Beschreibung
x | - | - | 1 | Roboterauto
- | x | - | 1 | Fahrgestell | - | x | - | 1 | Kameraeinheit
- | - | x | 8 | Abstandshülsen | - | - | x | 1 | Raspberry Pi Kamera
- | - | x | 3 | Bodenplatten | - | - | x | 1 | Halterung
- | - | x | 1 | Projektlogo | - | - | x | 1 | Flex Kabel
- | - | x |  | Schraube | - | x | - | 1 | Roboterarm
- | - | x |  | Mutter | - | - | x | 4 | Servomotor
- | x | - | 1 | Recheneinheit | - | - | x | 1 | Baukasten
- | - | x | 1 | Raspberry Pi 4 B | - | - | x | 1 | Motortreiber
- | - | x | 1 | Port Doubler | - | - | x |  | Jumper Kabel
- | - | x | 1 | Steckbrett | - | - | x | 1 | Voltage Translator
- | - | x | 1 | USB C Kabel | - | x | - | 1 | Akkueinheit
- | x | - | 1 | Motoreinheit | - | - | x | 4 | AA Akku 1,2 V
- | - | x | 4 | DC Motoren | - | - | x | 1 | AA Gehäuse
- | - | x | 1 | Motortreiber | - | - | x | 1 | Spezial-Akku 3,7 V
- | - | x | 4 | Drahtkabel | - | - | x | 1 | Lademodul
- | - | x |  | Jumper Kabel | - | - | x | 2 | Schalter
- | x | - | 1 | Sensoreinheit | - | - | x | 1 | USB A Kabel
- | - | x |  | Jumper Kabel | - | x | - | 1 | Noch nicht verbaut
- | - | x | 4 | Ultraschallsensor | - | - | x | 1 | Wireless Empfänger
- | - | x | 4 | Halterung | - | - | - | 1 | Beschleunigungssensor
- | - | x | 1 | Datenkabel | - | - | x | 1 | USB C in Kabel
- | - | x | 1 | Arduino atmega328
- | - | x | 1 | Steckbrett

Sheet: Info
Terminplan/Projektplan
Light-Version 2.2 vom 04.02.2017
Allgemeine Information über diese Vorlage
Mit dem Terminplaner oder auch Projektplaner kannst du deine Projekte einfach planen. Es stehen dir 60 Zeilen zur Planung bereit. Du kannst natürlich auch mehr Zeilen einfügen oder Zeilen entfernen. Die Zeitachse ist beliebig einstellbar. Gib einfach einen Starttermin ein und der Kalender wird automatisch erstellt. Bitte darauf achten, daß als Starttermin ein Montag gewählt wird.
Bedienungshinweise
Eine zusätzliche Zeile einfügen: Komplette Zeile markieren, kopieren und einfügen. So werden alle Formatierungen übernommen. Tipp: Gib als Kalenderstartdatum immer das Datum eines Montages ein. So werden die Kalenderwochen richtig angezeigt.
Was ist neu in Version 2.2
- Der Projektplan wurde optisch übersichtlicher gestaltet. - Die Jahreszahl wird nun im Monat angezeigt, z.B. Januar 17. Dadurch sind auch Projektpläne über mehrere Jahre möglich. - Wenn ein "x" für "Anzeige nur Arbeitstage" gesetzt ist, werden nun die Balken nicht mehr an den Wochenenden angezeigt. Samstag/Sonntag bleibt dann grau. - Meilensteine: Liegt ein Meilenstein in der Vergangenheit, wird dieser in rot dargestellt. Durch Eingabe eine "F" (für Fertig) kann der Meilenstein auf grün gesetzt werden. - Es steht nun eine Vorlage für den Kalenderzeitraum 12 Monate und eine Vorlage für 24 Monate zur Verfügung.
Allgemeine Hinweise
Die Tabelle ist offen, d.h. sie hat keinen Blattschutz. Es werden teilweise Formeln und bedingte Formatierungen verwendet. Daher bitte darauf achten, dass keine Formeln aus den Zellen gelöscht werden.
Auf
http://www.alle-meine-vorlagen.de/
stehen viele weitere Vorlagen zum Download bereit wie z.B.:
￭ Arbeitszeitnachweis
￭ Anwesenheitsliste
￭ Notenspiegel
￭ Hausaufgabenplaner
￭ AMV-Jahreskalender 2017
￭ Telefonnotiz
￭ Checkliste Campingurlaub
￭ Einfache ToDo-Liste
￭ Kassenbuch
￭ FotoDoku - Individuelle Fotodokumente schnell und einfach erstellen
um nur einige zu nennen…
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

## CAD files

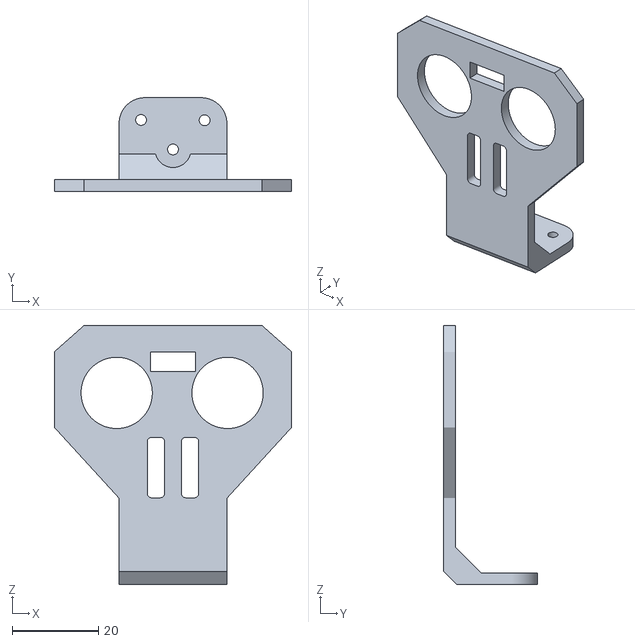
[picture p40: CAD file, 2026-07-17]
hw/ULTRASONIC_HOLDER.stl
55.0 x 21.7 x 60.0

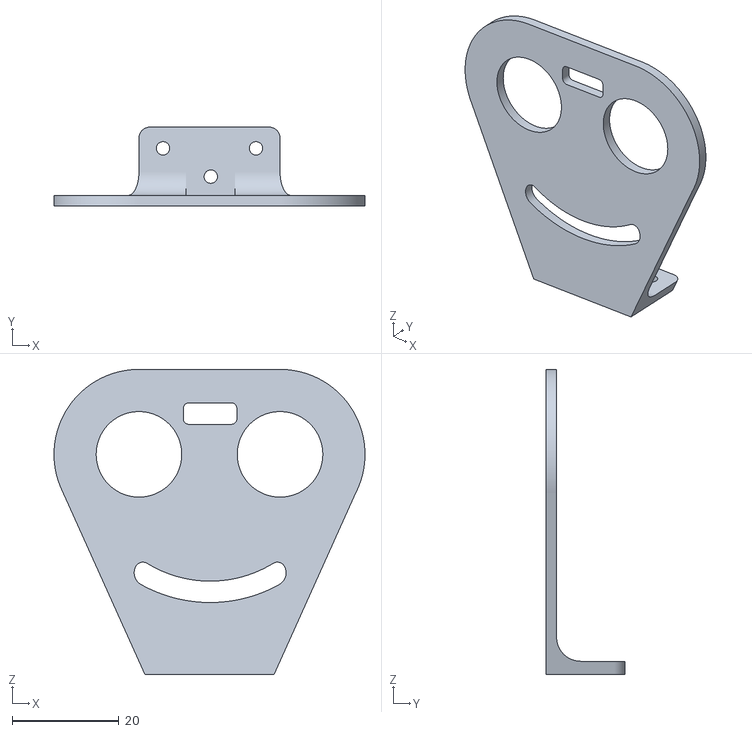
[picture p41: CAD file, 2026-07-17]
hw/New_Ultra_sonic_holder.stl
58.2 x 14.8 x 57.1

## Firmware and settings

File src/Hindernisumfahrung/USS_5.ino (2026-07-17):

#include <Arduino.h>

// Ein Sensor pro Richtung; die Reihenfolge legt das Offset-Schema fest,
// mit dem alle fünf Distanzen über eine einzige serielle Verbindung
// codiert werden (siehe encodeDistance()).
struct UltrasonicSensor {
  uint8_t trigPin;
  uint8_t echoPin;
  uint16_t offset;
};

const uint8_t SENSOR_COUNT = 5;
const uint16_t OFFSET_STEP = 500;
const unsigned long PULSE_TIMEOUT_US = 30000UL;  // ~5 m maximale Reichweite
const float US_TO_CM = 29.1f;
const int LOOP_DELAY_MS = 500;

UltrasonicSensor sensors[SENSOR_COUNT] = {
  {8, 9, 0 * OFFSET_STEP},    // Sensor 1 – Vorne
  {7, 10, 1 * OFFSET_STEP},   // Sensor 2 – Vorne Rechts
  {4, 5, 2 * OFFSET_STEP},    // Sensor 3 – Vorne Links
  {2, 3, 3 * OFFSET_STEP},    // Sensor 4 – Rechts
  {12, 11, 4 * OFFSET_STEP},  // Sensor 5 – Links
};

void setup() {
  for (uint8_t i = 0; i < SENSOR_COUNT; i++) {
    pinMode(sensors[i].trigPin, OUTPUT);
    pinMode(sensors[i].echoPin, INPUT);
  }
  Serial.begin(9600);
}

long measureDistanceCm(const UltrasonicSensor &sensor) {
  digitalWrite(sensor.trigPin, LOW);
  delayMicroseconds(2);
  digitalWrite(sensor.trigPin, HIGH);
  delayMicroseconds(10);
  digitalWrite(sensor.trigPin, LOW);

  long duration = pulseIn(sensor.echoPin, HIGH, PULSE_TIMEOUT_US);
  if (duration == 0) {
    return OFFSET_STEP - 1;  // kein Echo empfangen: als maximale Distanz werten
  }
  return (duration / 2) / US_TO_CM;
}

long encodeDistance(long distanceCm, uint16_t offset) {
  if (distanceCm >= OFFSET_STEP) {
    distanceCm = OFFSET_STEP - 1;
  }
  return distanceCm + offset;
}

void loop() {
  for (uint8_t i = 0; i < SENSOR_COUNT; i++) {
    long distanceCm = measureDistanceCm(sensors[i]);
    Serial.println(encodeDistance(distanceCm, sensors[i].offset));
    delay(LOOP_DELAY_MS);
  }
}

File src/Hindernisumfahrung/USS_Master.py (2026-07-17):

"""Raspberry-Pi-Master: liest die USS-Sensoren und steuert die Hindernisumfahrung."""

import logging

import Motortreiber as m
from Ultraschallsensoren import UltrasonicArray

logging.basicConfig(level=logging.INFO)
logger = logging.getLogger(__name__)


def choose_maneuver(distances: dict) -> None:
    """Wählt anhand der fünf Sensordistanzen das passende Ausweichmanöver."""
    vorne = distances["vorne"]
    vorne_rechts = distances["vorne_rechts"]
    vorne_links = distances["vorne_links"]
    rechts = distances["rechts"]
    links = distances["links"]

    if vorne < min(vorne_rechts, vorne_links, rechts, links):
        m.sharpLeft() if vorne_rechts < vorne_links else m.sharpRight()
    elif vorne_rechts < min(vorne, vorne_links, rechts, links):
        m.swiftForwardLeft()
    elif vorne_links < min(vorne, vorne_rechts, rechts, links):
        m.swiftForwardRight()
    elif rechts < min(vorne, vorne_links, vorne_rechts, links):
        m.swiftForwardLeft()
    elif links < min(vorne, vorne_links, rechts, vorne_rechts):
        m.swiftForwardRight()
    else:
        m.moveForward()


def main() -> None:
    with UltrasonicArray(port="/dev/ttyUSB0") as sensors:
        while True:
            distances = sensors.poll()
            logger.info("Sensordistanzen: %s", distances)
            choose_maneuver(distances)


if __name__ == "__main__":
    main()

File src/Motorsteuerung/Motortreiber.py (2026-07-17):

"""Fahrbefehle für Omega-Tron: benannte Manöver und kontinuierliches Mixing."""

import time
from typing import Final, Tuple

import RPi.GPIO as GPIO

from AMSpi import AMSpi

GPIO.setmode(GPIO.BCM)

_SHIFT_REGISTER_PINS: Final = (21, 20, 16)
_L293D_PWM_PINS: Final = (5, 6, 13, 19)
_COMMAND_HOLD_S: Final = 0.1


def _with_amspi() -> AMSpi:
    amspi = AMSpi()
    amspi.set_74HC595_pins(*_SHIFT_REGISTER_PINS)
    amspi.set_L293D_pins(*_L293D_PWM_PINS)
    return amspi


def moveBackward() -> None:
    with _with_amspi() as amspi:
        amspi.run_dc_motors([amspi.DC_Motor_1, amspi.DC_Motor_2, amspi.DC_Motor_3, amspi.DC_Motor_4], True, 100)
        time.sleep(_COMMAND_HOLD_S)


def moveForward() -> None:
    with _with_amspi() as amspi:
        amspi.run_dc_motors([amspi.DC_Motor_1, amspi.DC_Motor_2, amspi.DC_Motor_3, amspi.DC_Motor_4], False, 100)
        time.sleep(_COMMAND_HOLD_S)


def sharpRight() -> None:
    with _with_amspi() as amspi:
        amspi.run_dc_motor(amspi.DC_Motor_1, True, 100)
        amspi.run_dc_motor(amspi.DC_Motor_3, False, 100)
        amspi.run_dc_motor(amspi.DC_Motor_2, True, 100)
        amspi.run_dc_motor(amspi.DC_Motor_4, False, 100)
        time.sleep(_COMMAND_HOLD_S)


def sharpLeft() -> None:
    with _with_amspi() as amspi:
        amspi.run_dc_motor(amspi.DC_Motor_2, False, 100)
        amspi.run_dc_motor(amspi.DC_Motor_4, True, 100)
        amspi.run_dc_motor(amspi.DC_Motor_1, False, 100)
        amspi.run_dc_motor(amspi.DC_Motor_3, True, 100)
        time.sleep(_COMMAND_HOLD_S)


def swiftForwardRight() -> None:
    with _with_amspi() as amspi:
        amspi.run_dc_motor(amspi.DC_Motor_4, False, 10)
        amspi.run_dc_motor(amspi.DC_Motor_2, True, 100)
        amspi.run_dc_motor(amspi.DC_Motor_3, True, 0)
        amspi.run_dc_motor(amspi.DC_Motor_1, True, 100)
        time.sleep(_COMMAND_HOLD_S)


def swiftForwardLeft() -> None:
    with _with_amspi() as amspi:
        amspi.run_dc_motor(amspi.DC_Motor_4, True, 100)
        amspi.run_dc_motor(amspi.DC_Motor_2, False, 10)
        amspi.run_dc_motor(amspi.DC_Motor_1, True, 0)
        amspi.run_dc_motor(amspi.DC_Motor_3, True, 100)
        time.sleep(_COMMAND_HOLD_S)


def swiftBackwardRight() -> None:
    with _with_amspi() as amspi:
        amspi.run_dc_motor(amspi.DC_Motor_1, False, 80)
        amspi.run_dc_motor(amspi.DC_Motor_3, False, 100)
        amspi.run_dc_motor(amspi.DC_Motor_2, False, 50)
        amspi.run_dc_motor(amspi.DC_Motor_4, False, 30)
        time.sleep(_COMMAND_HOLD_S)


def swiftBackwardLeft() -> None:
    with _with_amspi() as amspi:
        amspi.run_dc_motor(amspi.DC_Motor_4, False, 80)
        amspi.run_dc_motor(amspi.DC_Motor_2, False, 100)
        amspi.run_dc_motor(amspi.DC_Motor_1, False, 50)
        amspi.run_dc_motor(amspi.DC_Motor_3, False, 30)
        time.sleep(_COMMAND_HOLD_S)


def stop() -> None:
    with _with_amspi() as amspi:
        amspi.stop_dc_motors([amspi.DC_Motor_1, amspi.DC_Motor_2, amspi.DC_Motor_3, amspi.DC_Motor_4])
        time.sleep(_COMMAND_HOLD_S)


def mix_differential_drive(speed: float, steering: float) -> Tuple[float, float]:
    """Berechnet die normierten Radgeschwindigkeiten aus Speed/Steering.

    Reine Funktion ohne Hardwarezugriff, damit die Mischlogik unabhängig
    von GPIO/AMSpi getestet werden kann.

    :param speed: Vorwärts-/Rückwärtsgeschwindigkeit im Bereich [-1.0, 1.0].
    :param steering: Lenkwert im Bereich [-1.0, 1.0]; negativ = links, positiv = rechts.
    :return: (left_speed, right_speed), je im Bereich [-1.0, 1.0].
    """
    speed = max(-1.0, min(1.0, speed))
    steering = max(-1.0, min(1.0, steering))

    left_speed = speed - steering
    right_speed = speed + steering
    # left_speed, right_speed = speed + steering, speed - steering  # Vorzeichen vertauscht, Auto lenkte spiegelverkehrt
    max_magnitude = max(abs(left_speed), abs(right_speed), 1.0)
    return left_speed / max_magnitude, right_speed / max_magnitude


def move(speed: float, steering: float, t: float = _COMMAND_HOLD_S) -> None:
    """Differentialantrieb aus kontinuierlichen Werten mischen.

    Wird von der Datensammlung (PS4-Steuerung), der CNN-Fahrt und der
    PID-geregelten Fahrspurfolge in main.py verwendet, die alle ein
    stufenloses Geschwindigkeits-/Lenksignal statt fester Manöver benötigen.
    Diese Funktion fehlte im Originalprojekt, obwohl sie von LogMain.py und
    Omega_Tron_CNN_Main.py bereits aufgerufen wurde.

    Annahme zur Radzuordnung (aus den sharpLeft/sharpRight-Manövern
    abgeleitet): DC_Motor_1/DC_Motor_3 = linke Seite, DC_Motor_2/DC_Motor_4
    = rechte Seite. Bei abweichender Verkabelung ggf. anpassen.

    :param speed: Vorwärts-/Rückwärtsgeschwindigkeit im Bereich [-1.0, 1.0].
    :param steering: Lenkwert im Bereich [-1.0, 1.0]; negativ = links, positiv = rechts.
    :param t: Dauer, für die der Befehl gehalten wird, in Sekunden.
    """
    left_speed, right_speed = mix_differential_drive(speed, steering)

    left_duty = int(abs(left_speed) * 100)
    right_duty = int(abs(right_speed) * 100)
    left_clockwise = left_speed >= 0
    right_clockwise = right_speed >= 0

    with _with_amspi() as amspi:
        amspi.run_dc_motor(amspi.DC_Motor_1, left_clockwise, left_duty)
        amspi.run_dc_motor(amspi.DC_Motor_3, left_clockwise, left_duty)
        amspi.run_dc_motor(amspi.DC_Motor_2, right_clockwise, right_duty)
        amspi.run_dc_motor(amspi.DC_Motor_4, right_clockwise, right_duty)
        time.sleep(t)

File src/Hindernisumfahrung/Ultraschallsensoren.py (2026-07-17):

"""Auslesen der fünf USS-Sensoren über die serielle Verbindung zum Arduino Nano.

Kapselt die Decodierung des Offset-Schemas aus USS_5.ino in eine
wiederverwendbare Klasse, damit sowohl die Hindernisumfahrung
(USS_Master.py) als auch die Müllerkennung (Detection_Modul.py) auf
dieselben Distanzwerte zugreifen können, statt den Sensor zweimal zu
initialisieren.

Erweiterungen gegenüber der ersten Fassung:
  - Jeder Sensor bekommt einen eigenen Medianfilter, da einzelne
    Fehlmessungen (Timeout, Mehrfachreflexion) sonst direkt in
    Ausweich-/Greifentscheidungen einfließen.
  - decode_raw_value() ist eine reine Funktion (kein self, kein I/O) und
    damit ohne echte serielle Verbindung testbar.
  - poll() versucht bei einem SerialException einen Reconnect statt
    abzustürzen, mit begrenzter Anzahl an Versuchen.
"""

import logging
import time
from typing import Dict, Optional

import serial

from filters import MedianFilter  # noqa: E402  (Pfad wird vom aufrufenden Skript ergänzt)

logger = logging.getLogger(__name__)

OFFSET_STEP = 500
SENSOR_NAMES = ("vorne", "vorne_rechts", "vorne_links", "rechts", "links")


def decode_raw_value(raw_value: float) -> Optional[Dict[str, float]]:
    """Decodiert einen rohen seriellen Messwert in {Sensorname: Distanz_cm}.

    Reine Funktion, damit das Offset-Schema unabhängig von einer echten
    seriellen Verbindung getestet werden kann.

    :return: Dictionary mit genau einem Eintrag, oder None bei ungültigem Wert.
    """
    sensor_index = int(raw_value // OFFSET_STEP)
    if not 0 <= sensor_index < len(SENSOR_NAMES):
        return None
    distance = raw_value - sensor_index * OFFSET_STEP
    return {SENSOR_NAMES[sensor_index]: distance}


class UltrasonicArray:
    """Liest, filtert und decodiert die Distanzwerte der fünf USS-Sensoren."""

    def __init__(self, port: str = "/dev/ttyUSB0", baudrate: int = 9600, timeout: float = 1.0,
                 median_window: int = 5, reconnect_delay_s: float = 2.0,
                 max_reconnect_attempts: int = 5) -> None:
        self._port = port
        self._baudrate = baudrate
        self._timeout = timeout
        self._reconnect_delay_s = reconnect_delay_s
        self._max_reconnect_attempts = max_reconnect_attempts

        self._serial = serial.Serial(port, baudrate, timeout=timeout)
        self._serial.flush()

        self._filters: Dict[str, MedianFilter] = {
            name: MedianFilter(window_size=median_window) for name in SENSOR_NAMES
        }
        self._last_distances: Dict[str, float] = {name: float(OFFSET_STEP) for name in SENSOR_NAMES}

    def _reconnect(self) -> bool:
        for attempt in range(1, self._max_reconnect_attempts + 1):
            logger.warning("USS-Verbindung verloren, Reconnect-Versuch %s/%s ...",
                            attempt, self._max_reconnect_attempts)
            try:
                self._serial.close()
            except serial.SerialException:
                pass
            time.sleep(self._reconnect_delay_s)
            try:
                self._serial = serial.Serial(self._port, self._baudrate, timeout=self._timeout)
                self._serial.flush()
                logger.info("USS-Verbindung wiederhergestellt.")
                return True
            except serial.SerialException:
                continue
        logger.error("USS-Reconnect nach %s Versuchen fehlgeschlagen. Fahre mit letzten bekannten Werten fort.",
                      self._max_reconnect_attempts)
        return False

    def poll(self) -> Dict[str, float]:
        """Liest alle aktuell im Puffer verfügbaren Messwerte, filtert sie und aktualisiert den Zustand.

        Bei einem Verbindungsabbruch wird versucht, neu zu verbinden; bis
        das gelingt (oder die Versuche aufgebraucht sind) werden die
        zuletzt bekannten, gefilterten Distanzen zurückgegeben, statt das
        Programm abstürzen zu lassen.

        :return: Die zuletzt bekannten, gefilterten Distanzen (in cm) aller fünf Sensoren.
        """
        try:
            while self._serial.in_waiting > 0:
                line = self._serial.readline().decode("utf-8", errors="ignore").strip()
                if not line:
                    continue
                try:
                    raw_value = float(line)
                except ValueError:
                    logger.warning("Konnte USS-Zeile nicht parsen: %r", line)
                    continue

                decoded = decode_raw_value(raw_value)
                if decoded is None:
                    logger.warning("Unerwarteter Rohwert von den USS-Sensoren: %s", raw_value)
                    continue

                for name, distance in decoded.items():
                    filtered = self._filters[name].update(distance)
                    self._last_distances[name] = filtered
        except serial.SerialException:
            self._reconnect()

        return dict(self._last_distances)

    def closest_sensor(self) -> str:
        """Name des Sensors mit der aktuell geringsten gefilterten Distanz."""
        distances = self.poll()
        return min(distances, key=distances.get)

    def close(self) -> None:
        if self._serial.is_open:
            self._serial.close()

    def __enter__(self) -> "UltrasonicArray":
        return self

    def __exit__(self, exc_type, exc_val, exc_tb) -> None:
        self.close()
